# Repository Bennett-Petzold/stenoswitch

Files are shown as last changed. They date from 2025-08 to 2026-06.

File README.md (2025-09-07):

Split stenography keyboard supporting USB, Bluetooth, battery, and embedded Plover translation.

# Warning!!!
There is no warranty, implied or otherwise, on this repository!
This is a hobby project by someone who has no formal education or training in PCB design. 
I _CANNOT_ guarantee that the battery circuit is safe.
I _CANNOT_ guarantee bluetooth communications comply with safety regulations.
I _AM NOT_ liable if you make this project and it is dysfunctional.
Understand that there is a risk of electrical fire due to the lithium ion battery.
Understand that wireless communications are untested and may interfere with pacemakers etc.

# Capabilities
TODO.

# Licenses
All code is licensed under the Mozilla Public License 2.0.
All non-code is licensed under CC BY-SA 4.0.
Both licenses allow for commercial use, but any commercial modification must be licensed under the same terms.
They will not "infect" other proprietary works.

# Subfolders
Each subfolder 

## Assembling the Project
See [assembly/README.md](assembly/README.md).

## PCB
KiCAD designs for printed circuit board.
See [pcb/README.md](pcb/README.md) for more.

## Software
Hardware-independent software built into the machine image.
Specialization to a specific hardware is handled in yocto.
See [software/README.md](software/README.md).

## Yocto Image
This defines the machine-specific image.
See [yocto/README.md](yocto/README.md).

# Releases
Some release resources are manually uploaded.
The initial install is done with the full disk image.
Subsequent updates are done by flashing ONLY the length of the full disk image.

# Appendix

### Steno Resources
* https://www.openstenoproject.org/plover/
* https://plover.wiki/index.php/Plover_Wiki
* https://lapwing.aerick.ca/
* https://www.artofchording.com/
* https://www.openstenoproject.org/learn-plover/home.html

### Approximate Cost
These are based on my costs (including shipping and taxes) September 2025, US address.
* $35 for keyswitches and lube
* $18 for springs
* $12 for battery
* $17 for Raspberry Pi
* $60 for components from DigiKey
* $50 for 5 PCBs both sides, 1 stencil from JLCPCB
Expect ~ $200 for a full single order.
There are electronics and buying in bulk reduces per-board prices.
Shipping is also a significant part of the price in these low quantities.

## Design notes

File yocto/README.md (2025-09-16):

# Build Scripts
* `source yocto/build_env.bash` to enter the build environment interactively.
* `scripts/run_build.bash` to build the distribution and partition.
* `scripts/make_image.bash` to create the disk image.

# Installing the Disk Image
To flash the disk image to media, write _ONLY_ the length of the disk image.
Any remaining space on the device is user scratch and retained between updates.

# Debug SSH over WiFi
## Configuring Connection
Set a static unique local IPv6 address. fd12:3456:789a:1::1 works.

# Build/Release Process
Builds use the upstream hash server to save time.
Yocto images are not currently built in Actions due to the memory requirement.
Contributors are responsible for locally validating Yocto builds.
A local Yocto build is manually added to releases.

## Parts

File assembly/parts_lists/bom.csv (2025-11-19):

Qty | Value | Purchase URL
40 | Cherry MX Style PCB Switch | https://mechanicalkeyboards.com/products/gateron-g-pro-30-silver-45g-linear-pcb-mount
1 | Raspberry Pi Zero v1.3 | https://www.digikey.com/en/products/detail/raspberry-pi/SC1176/15298147
1 | 1043 | https://www.digikey.com/en/products/detail/keystone-electronics/1043/2745669
1 | EVE 35V | https://www.18650batterystore.com/products/eve-35v-18650-3500mah-10a-battery
1 | MP2637GR-P | https://www.digikey.com/en/products/detail/monolithic-power-systems-inc/MP2637GR-P/5298904
1 | BQ27427YZFR | https://www.digikey.com/en/products/detail/texas-instruments/BQ27427YZFR/17748369
1 | 1uF | https://www.digikey.com/en/products/detail/samsung-electro-mechanics/CL21B105KAFNNNE/3886724
1 | RA1H1C112R | https://www.digikey.com/en/products/detail/e-switch/RA1H1C112R/3778069
1 | ERB-RE1R00V | https://www.digikey.com/en/products/detail/panasonic-electronic-components/ERB-RE1R00V/2796790
1 | DMG2305UX-7 | https://www.digikey.com/en/products/detail/diodes-incorporated/DMG2305UX-7/4340667
6 | 10K | https://www.digikey.com/en/products/detail/stackpole-electronics-inc/RMCF0805FT10K0/1760676
3 | SLW-864587-2A-RA-N-D | https://www.digikey.com/en/products/detail/same-sky-formerly-cui-devices/SLW-864587-2A-RA-N-D/24399384
1 | 2.2uH | https://www.digikey.com/en/products/detail/taiyo-yuden/BRL3225T2R2M/2002780
1 | 47nF | https://www.digikey.com/en/products/detail/walsin-technology-corporation/0805B473J500CT/9355080
1 | 20m | https://www.digikey.com/en/products/detail/stackpole-electronics-inc/CSS0805FT20L0/6271917
5 | ESD321DYAR | https://www.digikey.com/en/products/detail/texas-instruments/ESD321DYAR/17394968
3 | TSD05DYFR | https://www.digikey.com/en/products/detail/texas-instruments/TSD05DYFR/21298352
1 | MCP3204T-CI/SL | https://www.digikey.com/en/products/detail/microchip-technology/MCP3204T-CI-SL/319441
6 | 22uF | https://www.digikey.com/en/products/detail/samsung-electro-mechanics/CL31A226KAHNNNE/3888705
30 | 1N4148WX-TP | https://www.mccsemi.com/pdf/Products/1N4148WX(SOD-323).pdf
1 | UJ20-C-H-G-SMT-P16-TR | https://www.digikey.com/en/products/detail/same-sky-formerly-cui-devices/UJ20-C-H-G-SMT-P16-TR/24818595
2 | RJ45 | https://www.digikey.com/en/products/detail/keystone-electronics/942/5638364
1 | 31.6k | https://www.digikey.com/en/products/detail/stackpole-electronics-inc/RMCF0805FT31K6/1713019
1 | 0.1uF | https://www.digikey.com/en/products/detail/yageo/CC0805KRX7R9BB104/302874
1 | MCP40D19T-104E_LT | https://www.digikey.com/en/products/detail/microchip-technology/MCP40D19T-104E-LT/2163913
1 | 15k | https://www.digikey.com/en/products/detail/stackpole-electronics-inc/RMCF0805FT15K0/1760487
4 | 5.1K | https://www.digikey.com/en/products/detail/stackpole-electronics-inc/RNCF0805DTE5K10/6241868
1 | 21.5k | https://www.digikey.com/en/products/detail/stackpole-electronics-inc/RMCF0805FT21K5/1760114
1 | 500K | https://www.digikey.com/en/products/detail/stackpole-electronics-inc/RNCF0805BTE500K/6240086
1 | 73.2k | https://www.digikey.com/en/products/detail/stackpole-electronics-inc/RNCF0805DTE73K2/6241979
1 | 4.02K | https://www.digikey.com/en/products/detail/stackpole-electronics-inc/RNCP0805FTD4K02/2240247
1 | 590k | https://www.digikey.com/en/products/detail/stackpole-electronics-inc/RMCF0805FT590K/1760428
1 | 8.06k | https://www.digikey.com/en/products/detail/stackpole-electronics-inc/RNCP0805FTD8K06/2240259
1 | 7.15K | https://www.digikey.com/en/products/detail/stackpole-electronics-inc/RMCF0805FT7K15/1713329
1 | EG2208 | https://www.digikey.com/en/products/detail/e-switch/EG2208/301963
1 | TLV431BIDBZR | https://www.digikey.com/en/products/detail/texas-instruments/TLV431BIDBZR/705335
1 | 2.2uF | https://www.digikey.com/en/products/detail/tdk-corporation/C2012X7R1C225K125AB/569046
1 | Ferrite Ring | https://www.digikey.com/en/products/detail/epcos-tdk-electronics/B64290P0037X087/3913645
2 | Test Points | https://www.digikey.com/en/products/detail/same-sky-formerly-cui-devices/CPG-45-TH-TR/25666028
1 | 40Pos Header | https://www.digikey.com/en/products/detail/w%C3%BCrth-elektronik/61304021121/4846886

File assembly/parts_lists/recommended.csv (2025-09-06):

Name | Purchase URL
TS391SNL50 Solder Paste | https://www.digikey.com/en/products/detail/chip-quik-inc/TS391SNL50/7802219
18650 Case for Spare Batteries | https://www.18650batterystore.com/products/18650-battery-case-4x-18650
Ethernet Cable | https://www.digikey.com/en/products/detail/assmann-wsw-components/AMJG0808-0050-BKB-26/7653981
20g Springs | https://stenokeyboards.com/products/20-gram-springs
Lube for Springs | https://mechanicalkeyboards.com/products/mk-krytox-205g0-lube-5ml
USB-C Cable | N/A
Keycaps | N/A

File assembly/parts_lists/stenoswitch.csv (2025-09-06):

Reference | Qty | Value | DNP | Exclude from BOM | Exclude from Board | Footprint | Datasheet
A0,Asterisk0,Asterisk1,Asterisk2,Asterisk3,B0,D0,E0,F0,G0,H0,K0,L0,Number_Bar0,Number_Bar1,Number_Bar2,Number_Bar3,Number_Bar4,Number_Bar5,Number_Bar6,Number_Bar7,Number_Bar8,Number_Bar9,Number_Bar10,Number_Bar11,O0,P_{L}0,P_{R}0,R_{L}0,R_{R}0,S0,S1,S2,Spare0,Spare1,T_{L}0,T_{R}0,U0,W0,Z0 | 40 | SW_Push |  |  |  | PCM_Switch_Keyboard_Cherry_MX:SW_Cherry_MX_PCB | ~
A1 | 1 | Raspberry Pi Zero v1.3 |  |  |  | Raspberry_Pi_Zero_v.1.3_Hat:RASPI_ZERO_FULL | https://pinout.xyz/
BAT0 | 1 | 1043 |  |  |  | 1043:BAT_1043
Battery_Charger0 | 1 | MP2637GR-P |  |  |  | QFN-24_MP2637_MNP | https://www.monolithicpower.com/en/documentview/productdocument/index/version/2/document_type/Datasheet/lang/en/sku/MP2637GR-Z
Battery_Monitor0 | 1 | BQ27427YZFR |  |  |  | BQ27427YZFR:IC_BQ27427YZFR
BAT_Decouple0 | 1 | 1uF |  |  |  | Capacitor_SMD:C_0805_2012Metric | https://www.digikey.com/en/products/detail/samsung-electro-mechanics/CL21B105KAFNNNE/3886724
BAT_EN0 | 1 | RA1H1C112R |  |  |  | SW_RA1H1C112R_EWI | RA1H1C112R
BAT_Fuse0 | 1 | ERB-RE1R00V |  |  |  | ultra_librarian_footprints:FUSE_ERBRE_PAN | ERB-RE1R00V
BAT_MIN0 | 1 | DMG2305UX-7 |  |  |  | SOT91P240X110-3N_DMG2305UX-7
BIN_Pulldown0,RNTC_{H}0,RNTC_{L}0,R_{Pullup}0 | 4 | 10K |  |  |  | Resistor_SMD:R_0805_2012Metric | https://www.digikey.com/en/products/detail/stackpole-electronics-inc/RMCF0805FT10K0/1760676
BT_EN0,STORAGE_EN0,TRANSLATION_EN0 | 3 | SLW-864587-2A-RA-N-D |  |  |  | SW_SLW-864587-2A-RA-N-D
CHRG_Bypass0 | 1 | 2.2uH |  |  |  | Inductor_SMD:L_1210_3225Metric | https://www.digikey.com/en/products/detail/taiyo-yuden/BRL3225T2R2M/2002780
CHRG_Decouple0 | 1 | 47nF |  |  |  | Capacitor_SMD:C_0805_2012Metric | https://www.digikey.com/en/products/detail/walsin-technology-corporation/0805B473J500CT/9355080
CHRG_Shunt0 | 1 | 20m |  |  |  | Resistor_SMD:R_0805_2012Metric | https://www.digikey.com/en/products/detail/stackpole-electronics-inc/CSS0805FT20L0/6271917
CR0,CR1,CR2,CR3 | 4 | ESD321DYAR |  |  |  | SOT5x3_DYA_TEX | https://www.ti.com/lit/gpn/esd321
CR4 | 1 | TSD05DYFR |  |  |  | TVS_SOD2_DYF_TEX | https://www.ti.com/lit/gpn/tsd05
Current_Monitor0 | 1 | MCP3204T-CI/SL |  |  |  | SOIC14-N_MC_MCH | MCP3204T-CI/SL
C_{BATT}0,C_{BATT}1,C_{SYS}0,C_{SYS}1,C_{SYS}2,VBUS_Bypass0 | 6 | 22uF |  |  |  | Capacitor_SMD:C_1206_3216Metric | https://www.digikey.com/en/products/detail/samsung-electro-mechanics/CL31A226KAHNNNE/3888705
D_{As}0,D_{AS}1,D_{AS}2,D_{AS}3,D_{A}0,D_{B}0,D_{D}0,D_{E}0,D_{F}0,D_{G}0,D_{H}0,D_{K}0,D_{L}0,D_{NUM}0,D_{NUM}1,D_{O}0,D_{PL}0,D_{PR}0,D_{RL}0,D_{RR}0,D_{Spare}0,D_{Spare}1,D_{S}0,D_{S}1,D_{S}2,D_{TL}0,D_{TR}0,D_{U}0,D_{W}0,D_{Z}0 | 30 | 1N4148WX-TP |  |  |  | Diode_SMD:D_SOD-323 | https://www.mccsemi.com/pdf/Products/1N4148WX(SOD-323).pdf
J0 | 1 | UJ20-C-H-G-SMT-P16-TR |  |  |  | UJ20-C-H-G-SMT-P16-TR:SAMESKY_UJ20-C-H-G-SMT-P16-TR
Left_Plug0,Right_Plug0 | 2 | RJ45 |  |  |  | custom:8P8C_942 | ~
RFB_{H}0 | 1 | 31.6k |  |  |  | Resistor_SMD:R_0805_2012Metric | https://www.digikey.com/en/products/detail/stackpole-electronics-inc/RMCF0805FT31K6/1713019
RFB_{L}0,RLIM_{H}0 | 2 | 10k |  |  |  | Resistor_SMD:R_0805_2012Metric | https://www.digikey.com/en/products/detail/stackpole-electronics-inc/RMCF0805FT10K0/1760676
RLIM_Decouple0 | 1 | 0.1uF |  |  |  | Capacitor_SMD:C_0805_2012Metric | https://www.digikey.com/en/products/detail/yageo/CC0805KRX7R9BB104/302874
RLIM_{L}0 | 1 | MCP40D19T-104E_LT |  |  |  | SOT65P210X110-5N
RREG_{H}0 | 1 | 15k |  |  |  | Resistor_SMD:R_0805_2012Metric | https://www.digikey.com/en/products/detail/stackpole-electronics-inc/RMCF0805FT15K0/1760487
RREG_{L}0,RWIN_{L}0 | 2 | 5.1k |  |  |  | Resistor_SMD:R_0805_2012Metric | https://www.digikey.com/en/products/detail/stackpole-electronics-inc/RMCF0805FT5K10/1760394,https://www.digikey.com/en/products/detail/stackpole-electronics-i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
RWIN_{H}0 | 1 | 21.5k |  |  |  | Resistor_SMD:R_0805_2012Metric | https://www.digikey.com/en/products/detail/stackpole-electronics-inc/RMCF0805FT21K5/1760114
R_{HIST}0 | 1 | 500K |  |  |  | Resistor_SMD:R_0805_2012Metric | https://www.digikey.com/en/products/detail/stackpole-electronics-inc/RNCF0805BTE500K/6240086
R_{ISET}0 | 1 | 73.2k |  |  |  | Resistor_SMD:R_0805_2012Metric | https://www.digikey.com/en/products/detail/stackpole-electronics-inc/RNCF0805DTE73K2/6241979
R_{Lower}0 | 1 | 4.02K |  |  |  | Resistor_SMD:R_0805_2012Metric | https://www.digikey.com/en/products/detail/stackpole-electronics-inc/RNCP0805FTD4K02/2240247
R_{OLIM}0 | 1 | 590k |  |  |  | Resistor_SMD:R_0805_2012Metric | https://www.digikey.com/en/products/detail/stackpole-electronics-inc/RMCF0805FT590K/1760428
R_{Store}0 | 1 | 8.06k |  |  |  | Resistor_SMD:R_0805_2012Metric | https://www.digikey.com/en/products/detail/stackpole-electronics-inc/RNCP0805FTD8K06/2240259
R_{Upper}0 | 1 | 7.15K |  |  |  | Resistor_SMD:R_0805_2012Metric | https://www.digikey.com/en/products/detail/stackpole-electronics-inc/RMCF0805FT7K15/1713329
STORE_EN0 | 1 | EG2208 |  |  |  | SW_EG2208
USB_Default_Power_CC1,USB_Default_Power_CC2 | 2 | 5.1K |  |  |  | Resistor_SMD:R_0805_2012Metric | https://www.digikey.com/en/products/detail/stackpole-electronics-inc/RNCF0805DTE5K10/6241868
VBAT_PASS0 | 1 | TLV431BIDBZR |  |  |  | DBZ3 | https://www.ti.com/lit/gpn/tlv431b
VDD_Decouple0 | 1 | 2.2uF |  |  |  | Capacitor_SMD:C_0805_2012Metric | https://www.digikey.com/en/products/detail/tdk-corporation/C2012X7R1C225K125AB/569046

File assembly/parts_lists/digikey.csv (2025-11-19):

Qty | Part Number
1 | 2648-SC1176-ND
1 | 36-1043-ND
1 | 1589-1147-1-ND
1 | 296-BQ27427YZFRCT-ND
1 | 1276-1066-1-ND
1 | EG5626-ND
1 | P15124CT-ND
1 | DMG2305UX-7DICT-ND
6 | RMCF0805FT10K0CT-ND
3 | 2223-SLW-864587-2A-RA-N-D-ND
1 | 587-2165-1-ND
1 | 1292-1583-1-ND
1 | 738-CSS0805FT20L0CT-ND
5 | 296-ESD321DYARCT-ND
3 | 296-TSD05DYFRCT-ND
1 | MCP3204T-CI/SLCT-ND
6 | 1276-3047-1-ND
30 | 1N4148WXTPMSCT-ND
1 | 2223-UJ20-C-H-G-SMT-P16-TRCT-ND
2 | 36-942-ND
1 | RMCF0805FT31K6CT-ND
1 | 311-1140-1-ND
1 | MCP40D19T-104E/LTCT-ND
1 | RMCF0805FT15K0CT-ND
4 | 738-RNCF0805DTE5K10CT-ND
1 | 738-RMCF0805FT21K5CT-ND
1 | 738-RNCF0805BTE500KCT-ND
1 | 738-RNCF0805DTE73K2CT-ND
1 | RNCP0805FTD4K02CT-ND
1 | 738-RMCF0805FT590KCT-ND
1 | RNCP0805FTD8K06CT-ND
1 | RMCF0805FT7K15CT-ND
1 | EG1941-ND
1 | 296-17571-1-ND
1 | 445-1420-1-ND
2 | 2223-CPG-45-TH-TRCT-ND
1 | 61304021121
1 | B64290P0037X087

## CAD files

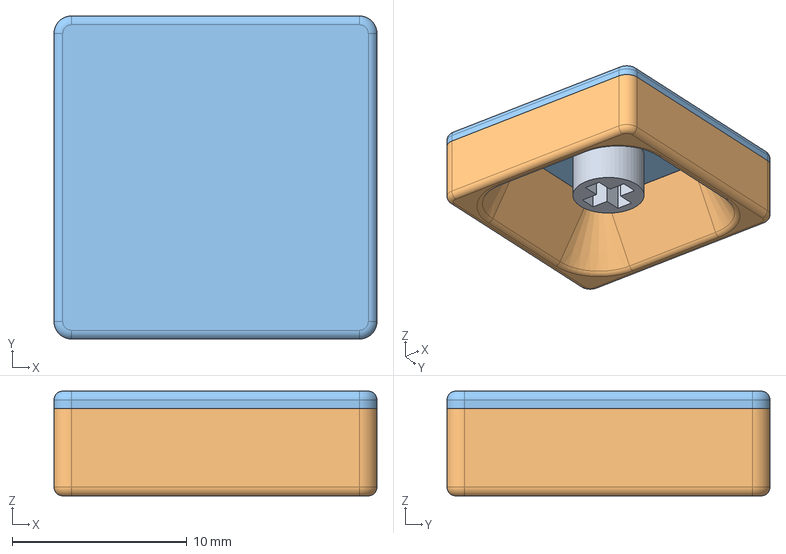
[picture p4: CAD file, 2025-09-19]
assembly/keycap/keycap.FCStd
18.5 x 18.5 x 6.00 mm
Stem001
Shell Bottom
ShellTop001

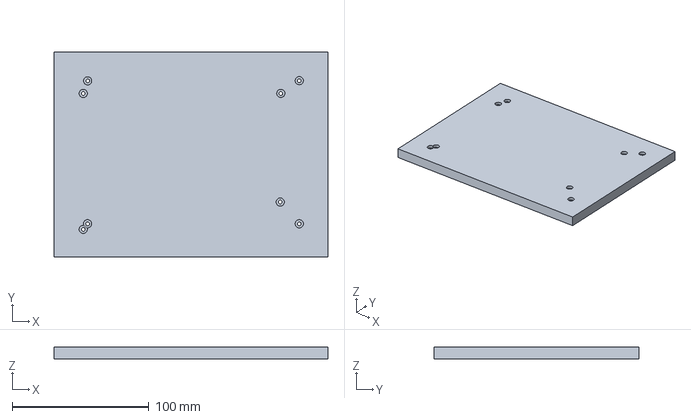
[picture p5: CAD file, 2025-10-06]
assembly/printed_aids/base_plate/base_plate.FCStd
200.0 x 150.0 x 9.00 mm

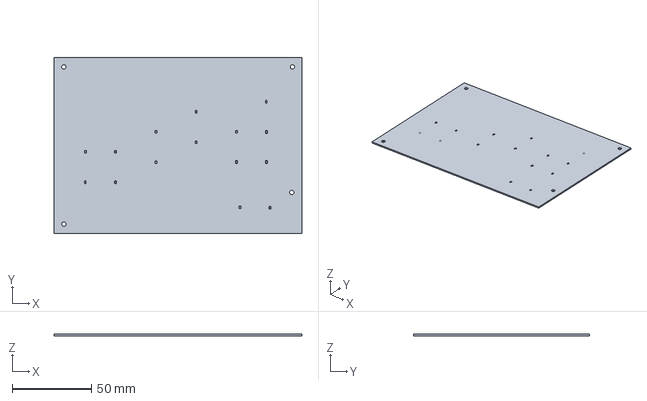
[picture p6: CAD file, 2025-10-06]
assembly/printed_aids/left_hand_plate/left_hand_plate.FCStd
156.4 x 110.8 x 1.00 mm

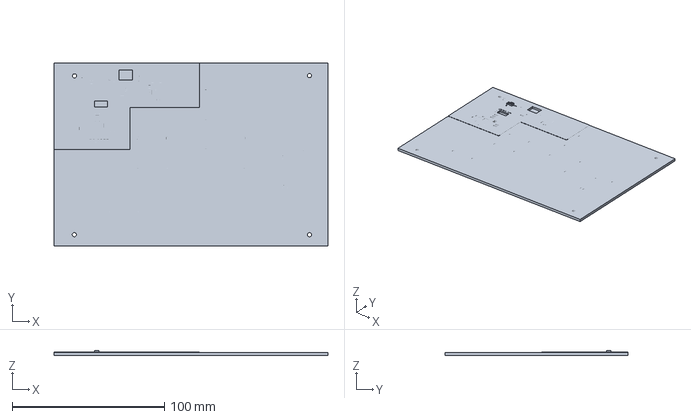
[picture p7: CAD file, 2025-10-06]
assembly/printed_aids/right_hand_plate/right_hand_plate.3mf
180.0 x 120.0 x 3.40 mm

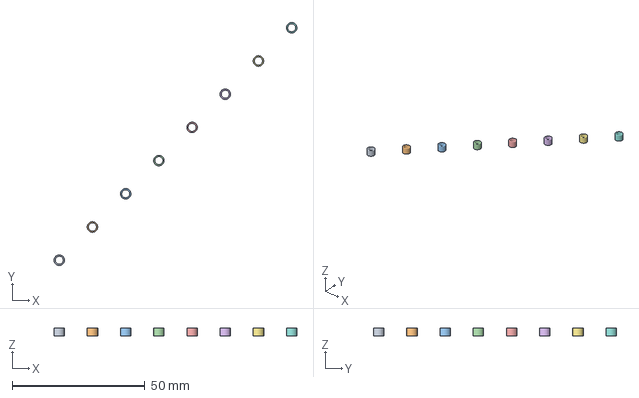
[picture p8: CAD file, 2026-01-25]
assembly/printed_aids/spacer/8spacer.3mf
91.5 x 91.5 x 3.10 mm

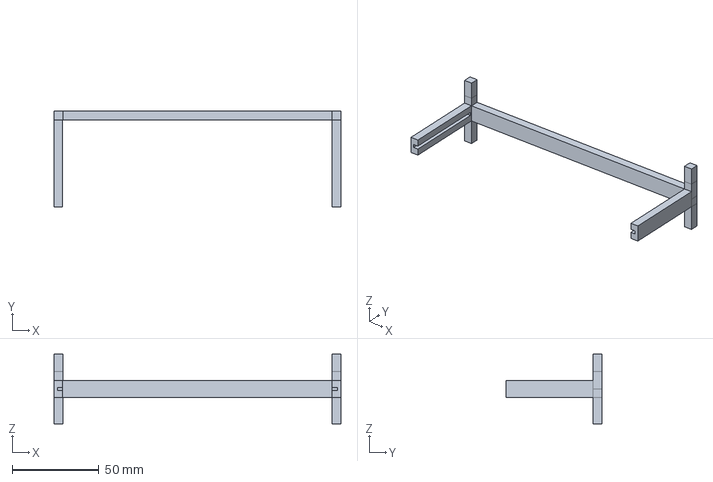
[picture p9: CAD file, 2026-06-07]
assembly/printed_aids/stand/stand.FCStd
165.0 x 55.0 x 40.0 mm

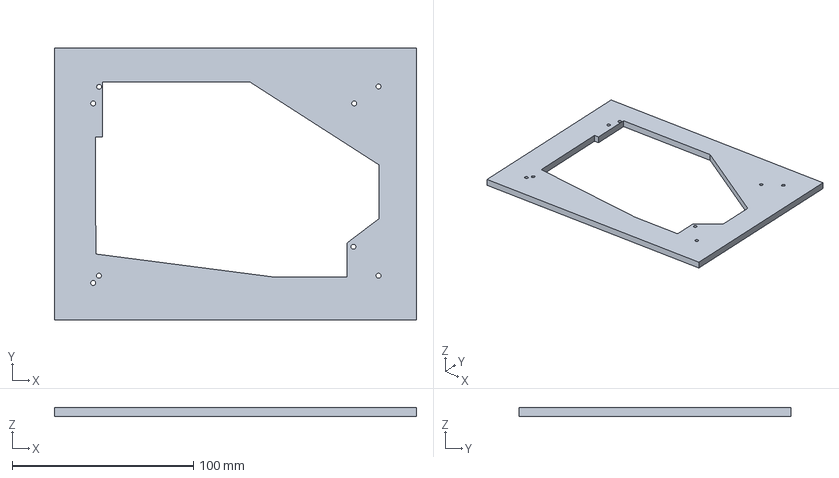
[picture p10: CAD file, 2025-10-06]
assembly/printed_aids/stencil_plate/stencil_plate.FCStd
200.0 x 150.0 x 5.00 mm

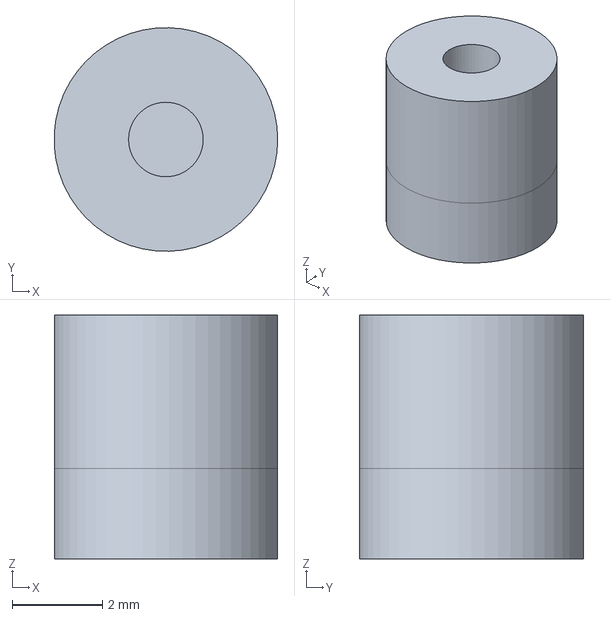
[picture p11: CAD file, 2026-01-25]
assembly/printed_aids/test_point_alignment/test_point_alignment_2.FCStd
4.95 x 4.95 x 5.40 mm

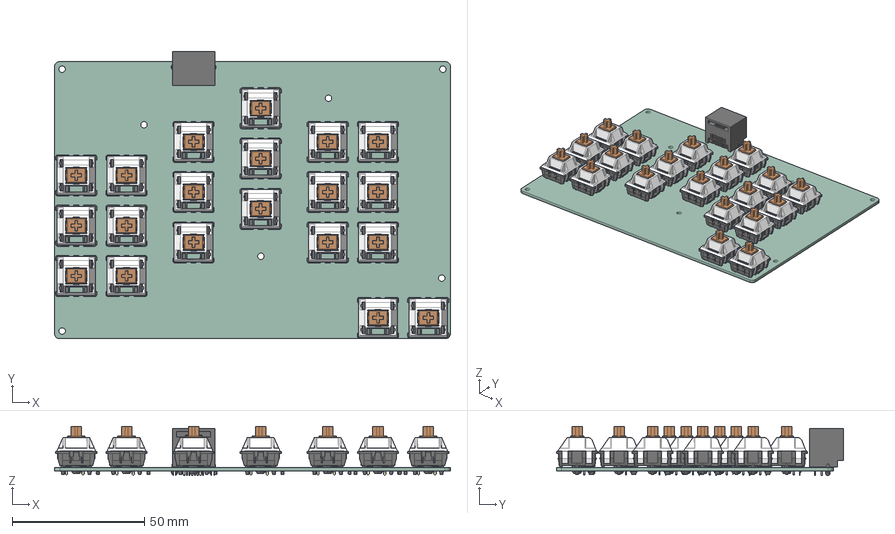
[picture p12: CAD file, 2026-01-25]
pcb/left_hand/left_hand.step
150.0 x 108.9 x 18.7 mm
SW_Cherry_MX_PCB x 20
D_SOD-323 x 15
left_hand_PCB

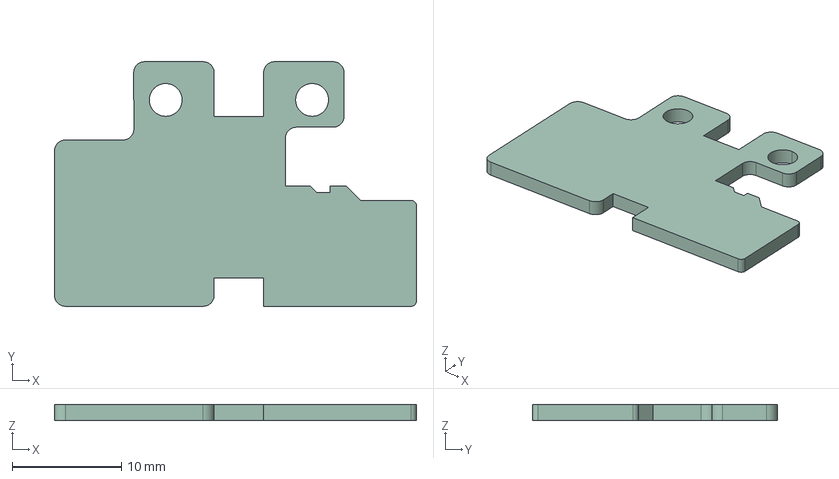
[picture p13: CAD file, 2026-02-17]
pcb/microsd_flipper/microsd_flipper.step
33.2 x 22.4 x 1.51 mm

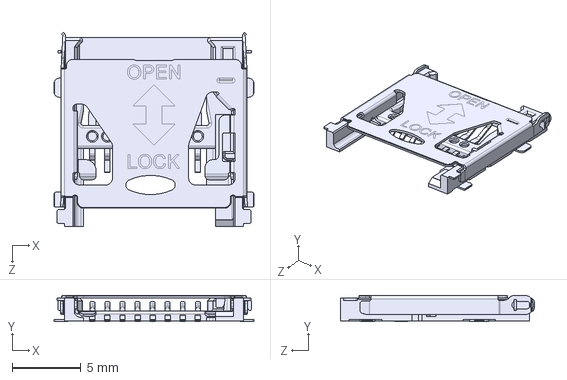
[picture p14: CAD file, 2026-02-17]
pcb/resources/snap_magic/MSD-10-C.step
14.6 x 1.90 x 14.2 mm

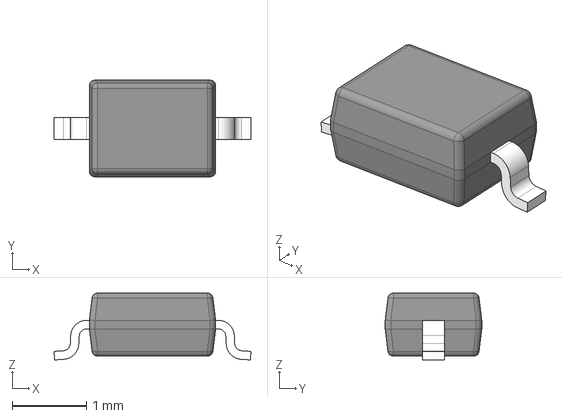
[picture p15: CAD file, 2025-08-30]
pcb/resources/ultra_librarian/DYF0002A.stp
2.65 x 1.30 x 0.9 mm
BODY-SOT
LEAD-SOT x 2

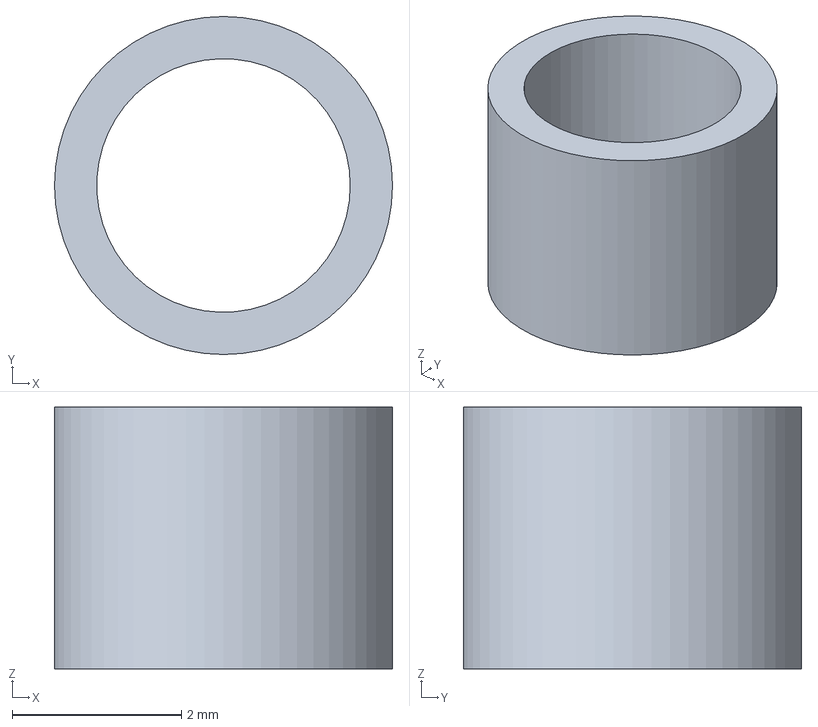
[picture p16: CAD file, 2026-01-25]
assembly/printed_aids/spacer/spacer.FCStd
4.00 x 4.00 x 3.10 mm

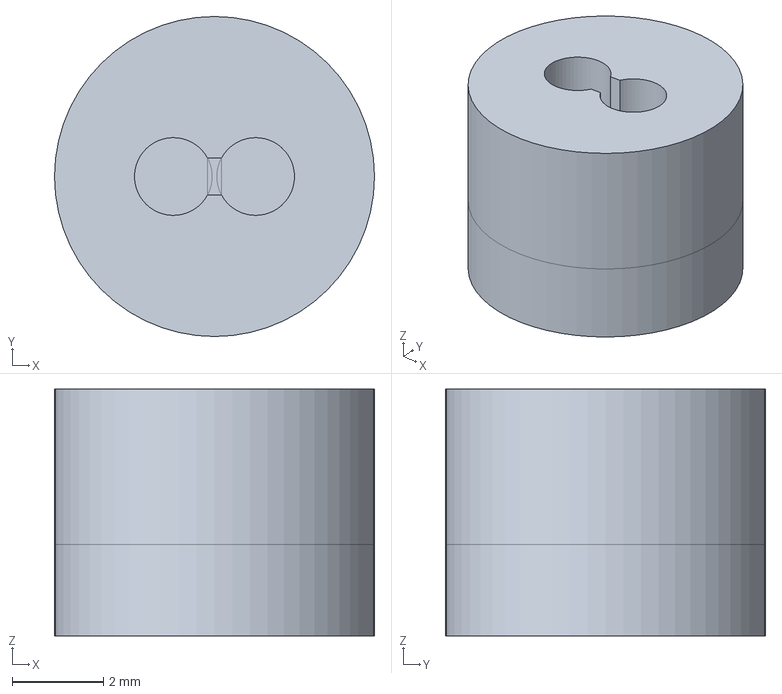
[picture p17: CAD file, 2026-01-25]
assembly/printed_aids/test_point_alignment/test_point_alignment_3.FCStd
7.00 x 7.00 x 5.40 mm

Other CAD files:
pcb/resources/snap_magic/UJ20-C-H-G-SMT-P16-TR.step
pcb/resources/ultra_librarian/DPL0002A.stp
assembly/printed_aids/test_point_alignment/test_point_alignment.FCStd
pcb/resources/snap_magic/0926-1-15-20-75-14-11-0.step
assembly/keycap/keycap.stl
assembly/printed_aids/base_plate/base_plate.3mf
assembly/printed_aids/base_plate/base_plate.stl
assembly/printed_aids/left_hand_plate/left_hand_plate.3mf
assembly/printed_aids/left_hand_plate/left_hand_plate.stl
assembly/printed_aids/right_hand_plate/right_hand_plate.stl
assembly/printed_aids/spacer/spacer.stl
assembly/printed_aids/stand/stand.3mf
assembly/printed_aids/stand/stand.stl
assembly/printed_aids/stencil_plate/stencil_plate.3mf
assembly/printed_aids/stencil_plate/stencil_plate.stl
assembly/printed_aids/test_point_alignment/test_point_alignment.3mf
assembly/printed_aids/test_point_alignment/test_point_alignment.stl
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

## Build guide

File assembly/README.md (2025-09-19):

TODO

## Keyswitches

#### Keyswitch Opener
https://www.printables.com/model/641731-over-engineered-3d-printed-switch-opener

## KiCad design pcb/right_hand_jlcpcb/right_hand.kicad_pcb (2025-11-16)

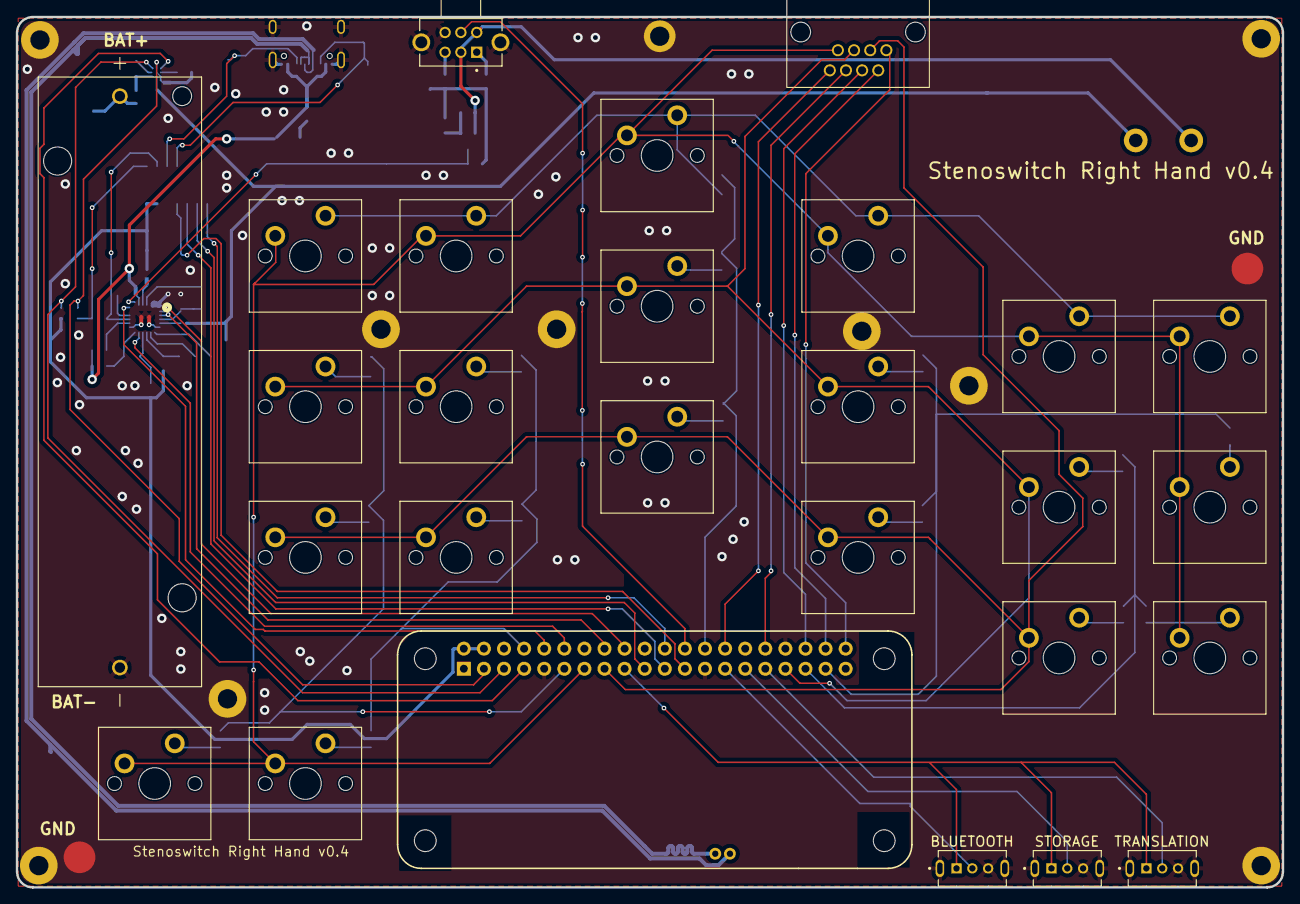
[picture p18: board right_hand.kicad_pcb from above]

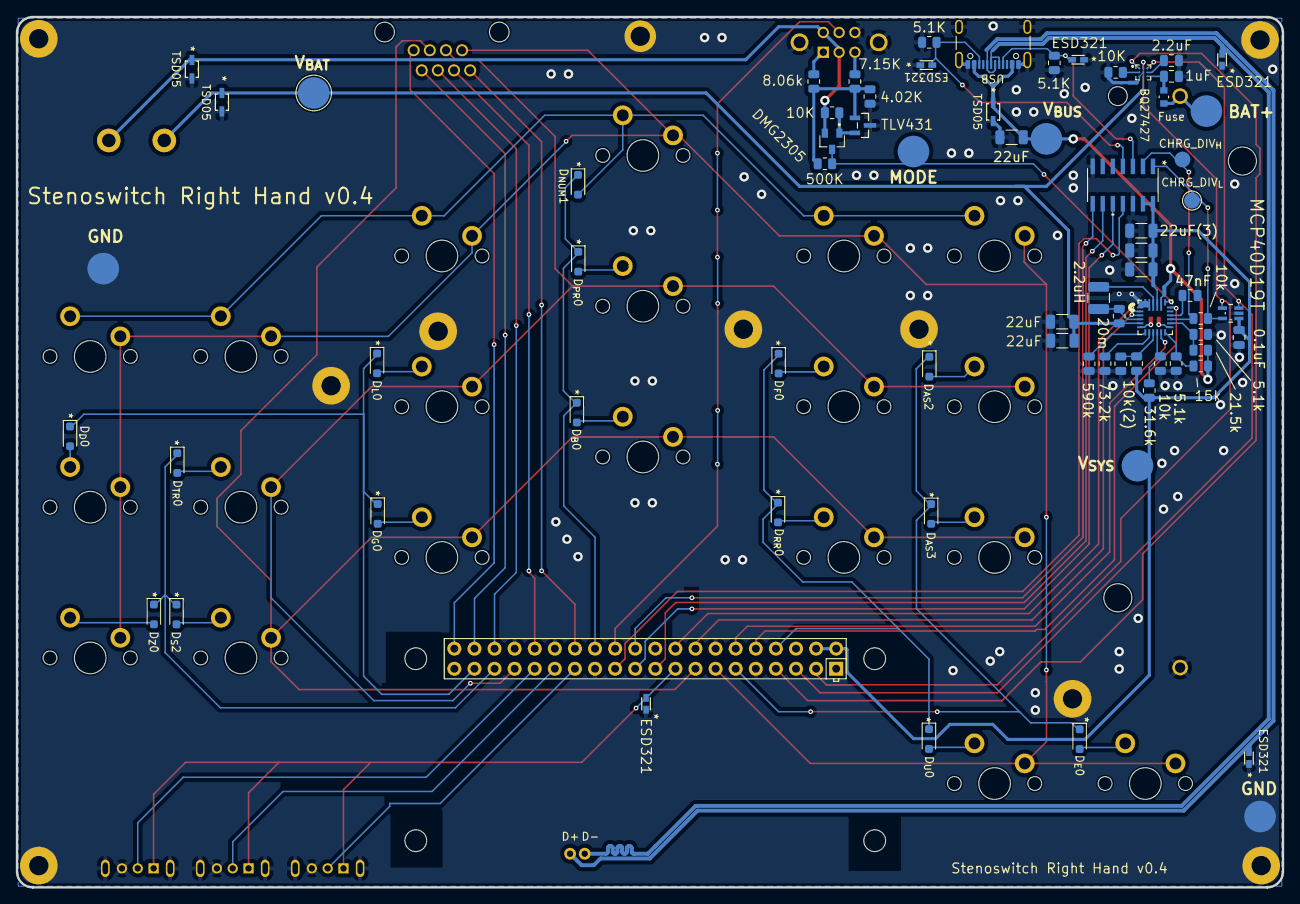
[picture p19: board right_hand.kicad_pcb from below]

Board: 2 copper layers, 160.0 x 110.0 mm, 96 parts (67 on the bottom side), 78 nets.

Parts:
A1: Raspberry Pi Zero v1.3; RASPI_ZERO_FULL
Asterisk2, Asterisk3: SW_Push; SW_Cherry_MX_PCB
B0: SW_Push; SW_Cherry_MX_PCB
BAT0: 1043; BAT_1043
BAT_Decouple0: 1uF; C_0805_2012Metric
BAT_EN0: RA1H1C112R; SW_RA1H1C112R_EWI
BAT_Fuse0: 2.5 A; FUSE_ERBRE_PAN
BAT_MIN0: DMG2305UX-7; SOT91P240X110-3N_DMG2305UX-7
BIN_Pulldown0: 10K; R_0805_2012Metric
BLUETOOTH: SLW-864587-2A-RA-N-D; SW_SLW-864587-2A-RA-N-D
Battery_Charger0: MP2637GR-P; QFN-24_MP2637_MNP
Battery_Monitor0: BQ27427YZFR; IC_BQ27427YZFR
CHRG_Bypass0: 2.2uH; L_1210_3225Metric
CHRG_DIV_{L}: TestPoint_Pad_D2.0mm
CHRG_Decouple0: 47nF; C_0805_2012Metric
CHRG_Shunt0: 20m; R_0805_2012Metric
CR0, CR1, CR3, CR4, CR5: ESD321DYAR; SOT5x3_DYA_TEX
CR2, CR6, CR7: TSD05DYFR; TVS_SOD2_DYF_TEX
C_{BATT}0, C_{BATT}1: 22uF; C_1206_3216Metric
C_{SYS}0, C_{SYS}1, C_{SYS}2: 22uF; C_1206_3216Metric
Current_Monitor1: MCP3204T-CI/SL; SOIC14-N_MC_MCH
D0: SW_Push; SW_Cherry_MX_PCB
D_{AS}2, D_{AS}3: 1N4148WX-TP; D_SOD-323_HandSoldering
D_{B}0: 1N4148WX-TP; D_SOD-323_HandSoldering
D_{D}0: 1N4148WX-TP; D_SOD-323_HandSoldering
D_{E}0: 1N4148WX-TP; D_SOD-323_HandSoldering
D_{F}0: 1N4148WX-TP; D_SOD-323_HandSoldering
D_{G}0: 1N4148WX-TP; D_SOD-323_HandSoldering
D_{L}0: 1N4148WX-TP; D_SOD-323_HandSoldering
D_{NUM}1: 1N4148WX-TP; D_SOD-323_HandSoldering
D_{PR}0: 1N4148WX-TP; D_SOD-323_HandSoldering
D_{RR}0: 1N4148WX-TP; D_SOD-323_HandSoldering
D_{S}2: 1N4148WX-TP; D_SOD-323_HandSoldering
D_{TR}0: 1N4148WX-TP; D_SOD-323_HandSoldering
D_{U}0: 1N4148WX-TP; D_SOD-323_HandSoldering
D_{Z}0: 1N4148WX-TP; D_SOD-323_HandSoldering
E0: SW_Push; SW_Cherry_MX_PCB
F0: SW_Push; SW_Cherry_MX_PCB
G0: SW_Push; SW_Cherry_MX_PCB
L0: SW_Push; SW_Cherry_MX_PCB
NT0, NT1, NT2, NT3, NT4: NetTie_2; NetTie-2_SMD_Pad0.5mm
Number_Bar6, Number_Bar7, Number_Bar8, Number_Bar9, Number_Bar10, Number_Bar11: SW_Push; SW_Cherry_MX_PCB
P_{R}0: SW_Push; SW_Cherry_MX_PCB
RFB_{H}0: 31.6k; R_0805_2012Metric
RFB_{L}0: 10k; R_0805_2012Metric
RLIM_Decouple0: 0.1uF; C_0805_2012Metric
RLIM_{H}0: 10k; R_0805_2012Metric
RLIM_{L}0: MCP40D19T-104E_LT; SOT65P210X110-5N
RNTC_{H}0: 10k; R_0805_2012Metric
RNTC_{L}0: 10k; R_0805_2012Metric
RREG_{H}0: 15k; R_0805_2012Metric
RREG_{L}0: 5.1k; R_0805_2012Metric
RWIN_{H}0: 21.5k; R_0805_2012Metric
RWIN_{L}0: 5.1k; R_0805_2012Metric
R_{HIST}0: 500K; R_0805_2012Metric
R_{ISET}0: 73.2k; R_0805_2012Metric
R_{Lower}0: 4.02K; R_0805_2012Metric
R_{OLIM}0: 590k; R_0805_2012Metric
R_{Pullup}0: 10K; R_0805_2012Metric
R_{R}0: SW_Push; SW_Cherry_MX_PCB
R_{Store}0: 8.06k; R_0805_2012Metric
R_{Upper}0: 7.15K; R_0805_2012Metric
Right_Plug0: RJ45; 8P8C_942
S2: SW_Push; SW_Cherry_MX_PCB
STORAGE: SLW-864587-2A-RA-N-D; SW_SLW-864587-2A-RA-N-D
STORE_EN0: EG2208; SW_EG2208
TRANSLATION: SLW-864587-2A-RA-N-D; SW_SLW-864587-2A-RA-N-D
T_{R}0: SW_Push; SW_Cherry_MX_PCB
U0: SW_Push; SW_Cherry_MX_PCB
USB0: USB4105-GF-A; USB_C_Receptacle_GCT_USB4105-xx-A_16P_TopMnt_Horizontal
USB_Default_Power_CC1, USB_Default_Power_CC2: 5.1K; R_0805_2012Metric
VBAT_PASS0: TLV431BIDBZR; DBZ3
VBUS_Bypass0: 22uF; C_1206_3216Metric
VDD_Decouple0: 2.2uF; C_0805_2012Metric
Z0: SW_Push; SW_Cherry_MX_PCB

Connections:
/Control/ALERT_{BATMON}: A1.7 (GP4), Battery_Monitor0.A1 (GPOUT)
/Control/BAT_{ON}: A1.16 (GP23), Battery_Charger0.3 (*BOOST)
/Control/CHG_{EN}: A1.10 (GP15/RXD), Battery_Charger0.18 (EN)
/Control/CHG_{ON}: A1.18 (GP24), Battery_Charger0.2 (*CHG)
/Control/CLK_{CURRENT}: A1.23 (GP11/SCLK), Current_Monitor1.11 (CLK)
/Control/CS_{CURRENT}: A1.22 (GP25), Current_Monitor1.8 (*CS/SHDN)
/Control/DIN_{CURRENT}: A1.19 (GP10/MOSI), Current_Monitor1.9 (DIN)
/Control/DOUT_{CURRENT}: A1.21 (GP9/MISO), Current_Monitor1.10 (DOUT)
/Control/Data_N: A1.PP23 (USB_D-), CR0.1, USB0.A7 (D-), USB0.B7 (D-)
/Control/Data_P: A1.PP22 (USB_D+), CR1.1, USB0.A6 (D+), USB0.B6 (D+)
/Control/Right_Columns0: A1.35 (GP19), D_{S}2.1 (K), D_{TR}0.1 (K), D_{Z}0.1 (K)
/Control/Right_Columns1: A1.37 (GP26), D_{D}0.1 (K), D_{G}0.1 (K), D_{L}0.1 (K)
/Control/Right_Columns2: A1.26 (GP7/CS1), D_{B}0.1 (K), D_{NUM}1.1 (K), D_{PR}0.1 (K)
/Control/Right_Columns3: A1.8 (GP14/TXD), D_{F}0.1 (K), D_{RR}0.1 (K), D_{U}0.1 (K)
/Control/Right_Columns4: A1.11 (GP17), D_{AS}2.1 (K), D_{AS}3.1 (K), D_{E}0.1 (K)
/Control/SCL: A1.5 (GP3/SCL), Battery_Monitor0.A3 (SCL), RLIM_{L}0.3 (SCL)
/Control/SDA: A1.3 (GP2/SDA), Battery_Monitor0.A2 (SDA), RLIM_{L}0.4 (SDA)
/Control/STORE_{ON}: A1.24 (GP8/CS0), STORE_EN0.5
/Control/USB_{ON}: A1.12 (GP18), Battery_Charger0.11 (*ACOK)
/Control/V_{SYS}: A1.2 (+5V), A1.4 (+5V), C_{SYS}0.1, C_{SYS}1.1, C_{SYS}2.1, Current_Monitor1.13 (VREF), Current_Monitor1.14 (VDD), NT0.1, RFB_{H}0.2, RLIM_Decouple0.1, RLIM_{L}0.1 (VDD), RNTC_{H}0.1
/Interface/Battery/CHRG_DIV_{H}: Battery_Charger0.15 (ILIM), Current_Monitor1.2 (CH1), RLIM_{H}0.1
/Interface/Battery/CHRG_DIV_{L}: CHRG_DIV_{L}.1, Current_Monitor1.1 (CH0), RLIM_{H}0.2, RLIM_{L}0.5 (W)
/Interface/Battery/V_{BUS}: CR2.1 (I/O), NT1.2, RREG_{H}0.1, RWIN_{H}0.1, USB0.A4 (VBUS), USB0.A9 (VBUS), USB0.B4 (VBUS), USB0.B9 (VBUS), VBUS_Bypass0.1
/Left_Columns0: A1.28 (GP1), Right_Plug0.4
/Left_Columns1: A1.32 (GP12/PWM0), Right_Plug0.3
/Left_Columns2: A1.36 (GP16), Right_Plug0.2
/Left_Columns3: A1.38 (GP20), Right_Plug0.1
/Left_Columns4: A1.40 (GP21), Right_Plug0.5
/Rows0: A1.33 (GP13/PWM1), Asterisk2.1, F0.1, L0.1, P_{R}0.1, Right_Plug0.7, T_{R}0.1
/Rows1: A1.15 (GP22), Asterisk3.1, B0.1, G0.1, R_{R}0.1, Right_Plug0.6, S2.1
/Rows2: A1.13 (GP27), D0.1, E0.1, Number_Bar6.1, Number_Bar7.1, Number_Bar8.1, Number_Bar9.1, Number_Bar10.1, Number_Bar11.1, Right_Plug0.8, U0.1, Z0.1
GND: A1.9 (GND), A1.14 (GND), A1.25 (GND), A1.30 (GND), A1.34 (GND), BAT0.N, BAT_Decouple0.2, BIN_Pulldown0.1, BLUETOOTH.3, BLUETOOTH.SH1, BLUETOOTH.SH2, Battery_Charger0.1 (PGND), Battery_Charger0.23 (PGND), Battery_Charger0.24 (PGND), CHRG_Decouple0.2, CR0.2, CR1.2, CR2.2 (GND), CR3.2, CR4.2, CR5.2, CR6.2 (GND), CR7.2 (GND), C_{BATT}0.2, C_{BATT}1.2, C_{SYS}0.2, C_{SYS}1.2, C_{SYS}2.2, Current_Monitor1.7 (DGND), Current_Monitor1.12 (AGND), NT2.1, NT3.2, NT4.2, RFB_{L}0.1, RLIM_Decouple0.2, RLIM_{L}0.2 (VSS), RNTC_{L}0.2, RREG_{L}0.2, RWIN_{L}0.2, R_{ISET}0.2, R_{Lower}0.2, R_{OLIM}0.2, STORAGE.3, STORAGE.SH1, STORAGE.SH2, STORE_EN0.6, STORE_EN0.S1, STORE_EN0.S2, TRANSLATION.3, TRANSLATION.SH1, TRANSLATION.SH2, USB0.A1 (GND), USB0.A12 (GND), USB0.B1 (GND), USB0.B12 (GND), USB0.S1 (SHIELD), USB_Default_Power_CC1.2, USB_Default_Power_CC2.2, VBAT_PASS0.3 (ANODE), VBUS_Bypass0.2, VDD_Decouple0.2
unnamed: A1.17 (+3V3), BLUETOOTH.1, CR5.1, STORAGE.1, TRANSLATION.1
unnamed: A1.27 (GP0), BLUETOOTH.2
unnamed: A1.29 (GP5), STORAGE.2
unnamed: A1.31 (GP6), TRANSLATION.2
unnamed: BAT0.P, BAT_Fuse0.2
unnamed: Battery_Charger0.6 (AGND), NT4.1
unnamed: BAT_EN0.2, Battery_Charger0.5 (BATT), Battery_Monitor0.C2 (SRX), CHRG_Shunt0.1, CR6.1 (I/O), C_{BATT}0.1, C_{BATT}1.1
unnamed: Battery_Charger0.4 (CSP), CHRG_Bypass0.1, CHRG_Shunt0.2
unnamed: Battery_Charger0.10 (FB), RFB_{H}0.1, RFB_{L}0.2
unnamed: Battery_Charger0.8 (ISET), R_{ISET}0.1
unnamed: BAT_MIN0.3, Battery_Charger0.19 (MODE), R_{HIST}0.1
unnamed: Battery_Charger0.9 (NTC), RNTC_{H}0.2, RNTC_{L}0.1
unnamed: Battery_Charger0.7 (OLIM), R_{OLIM}0.1
unnamed: Battery_Charger0.14 (PWIN), RWIN_{H}0.2, RWIN_{L}0.1
unnamed: Battery_Charger0.12 (REG), RREG_{H}0.2, RREG_{L}0.1
unnamed: Battery_Charger0.22 (SW), CHRG_Bypass0.2
unnamed: Battery_Charger0.21 (SYS), NT0.2
unnamed: Battery_Charger0.13 (TMR), NT3.1
unnamed: Battery_Charger0.16 (VCC), CHRG_Decouple0.1
unnamed: Battery_Charger0.20 (VIN), NT1.1
unnamed: BAT_Decouple0.1, BAT_Fuse0.1, Battery_Monitor0.C3 (BAT)
unnamed: BIN_Pulldown0.2, Battery_Monitor0.B1 (BIN)
unnamed: Battery_Monitor0.B3 (VDD), VDD_Decouple0.1
unnamed: Battery_Monitor0.B2 (VSS), Battery_Monitor0.C1 (VSS__1), NT2.2
unnamed: BAT_EN0.1, BAT_MIN0.2, CR7.1 (I/O), R_{Pullup}0.1, STORE_EN0.2, STORE_EN0.4
unnamed: CR3.1, Current_Monitor1.3 (CH2), USB0.B5 (CC2), USB_Default_Power_CC2.1
unnamed: CR4.1, Current_Monitor1.4 (CH3), USB0.A5 (CC1), USB_Default_Power_CC1.1
unnamed: Asterisk2.2, D_{AS}2.2 (A)
unnamed: Asterisk3.2, D_{AS}3.2 (A)
unnamed: B0.2, D_{B}0.2 (A)
unnamed: D0.2, D_{D}0.2 (A)
unnamed: D_{E}0.2 (A), E0.2
unnamed: D_{F}0.2 (A), F0.2
unnamed: D_{G}0.2 (A), G0.2
unnamed: D_{L}0.2 (A), L0.2
unnamed: D_{NUM}1.2 (A), Number_Bar6.2, Number_Bar7.2, Number_Bar8.2, Number_Bar9.2, Number_Bar10.2, Number_Bar11.2
unnamed: D_{PR}0.2 (A), P_{R}0.2
unnamed: D_{RR}0.2 (A), R_{R}0.2
unnamed: D_{S}2.2 (A), S2.2
unnamed: D_{TR}0.2 (A), T_{R}0.2
unnamed: D_{U}0.2 (A), U0.2
unnamed: D_{Z}0.2 (A), Z0.2
unnamed: R_{Store}0.1, STORE_EN0.1
unnamed: R_{Upper}0.1, STORE_EN0.3
unnamed: BAT_MIN0.1, R_{Pullup}0.2, VBAT_PASS0.2 (CATHODE)
unnamed: R_{HIST}0.2, R_{Lower}0.1, R_{Store}0.2, R_{Upper}0.2, VBAT_PASS0.1 (REF)

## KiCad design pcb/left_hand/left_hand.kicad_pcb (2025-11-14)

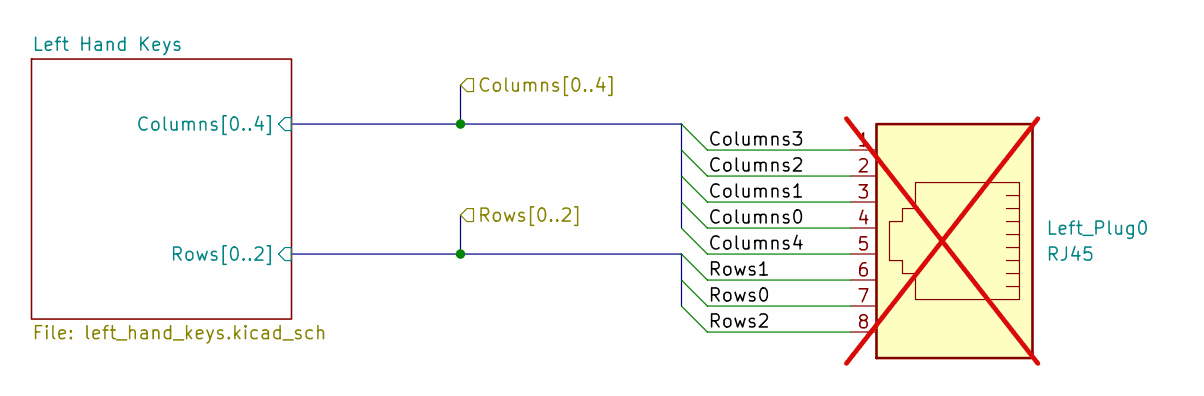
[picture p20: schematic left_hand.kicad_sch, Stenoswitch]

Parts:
Left_Plug0: RJ45; 8P8C_942; not fitted

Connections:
/Columns0: Left_Plug0.4; also elsewhere on the board
/Columns1: Left_Plug0.3; also elsewhere on the board
/Columns2: Left_Plug0.2; also elsewhere on the board
/Columns3: Left_Plug0.1; also elsewhere on the board
/Columns4: Left_Plug0.5; also elsewhere on the board
/Rows0: Left_Plug0.7; also elsewhere on the board
/Rows1: Left_Plug0.6; also elsewhere on the board
/Rows2: Left_Plug0.8; also elsewhere on the board

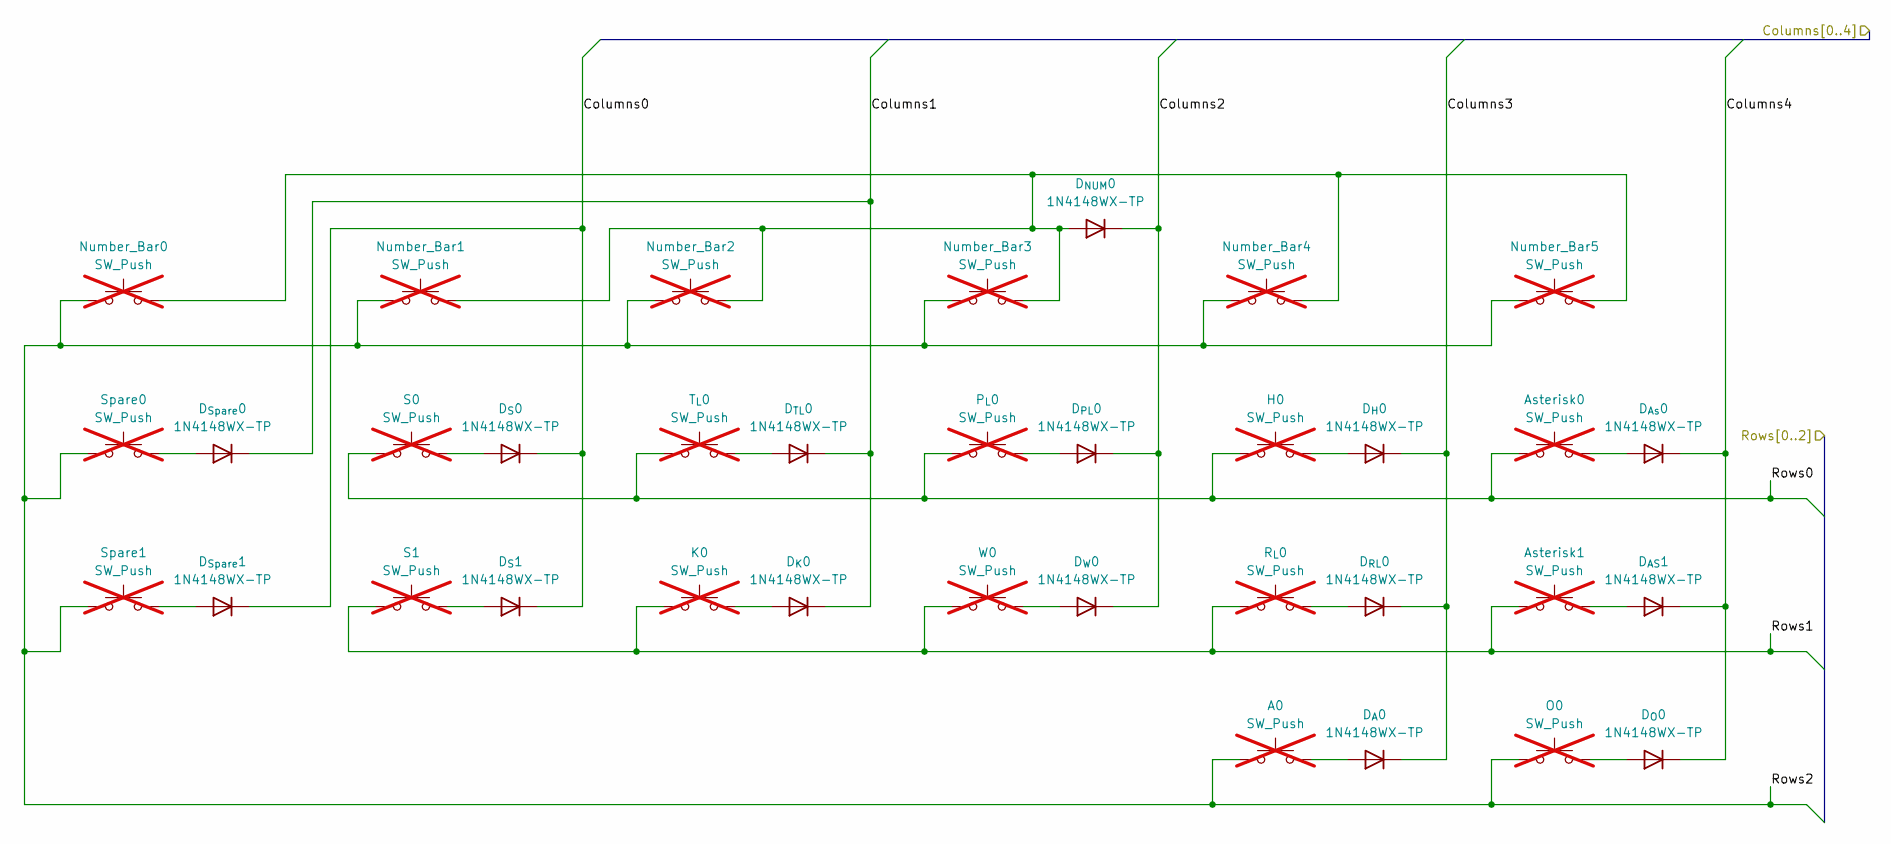
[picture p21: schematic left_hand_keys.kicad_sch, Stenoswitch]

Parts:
A0: SW_Push; SW_Cherry_MX_PCB; not fitted
Asterisk0, Asterisk1: SW_Push; SW_Cherry_MX_PCB; not fitted
D_{AS}1: 1N4148WX-TP; D_SOD-323; LCSC C78740
D_{As}0: 1N4148WX-TP; D_SOD-323; LCSC C78740
D_{A}0: 1N4148WX-TP; D_SOD-323; LCSC C78740
D_{H}0: 1N4148WX-TP; D_SOD-323; LCSC C78740
D_{K}0: 1N4148WX-TP; D_SOD-323; LCSC C78740
D_{NUM}0: 1N4148WX-TP; D_SOD-323; LCSC C78740
D_{O}0: 1N4148WX-TP; D_SOD-323; LCSC C78740
D_{PL}0: 1N4148WX-TP; D_SOD-323; LCSC C78740
D_{RL}0: 1N4148WX-TP; D_SOD-323; LCSC C78740
D_{Spare}0, D_{Spare}1: 1N4148WX-TP; D_SOD-323; LCSC C78740
D_{S}0, D_{S}1: 1N4148WX-TP; D_SOD-323; LCSC C78740
D_{TL}0: 1N4148WX-TP; D_SOD-323; LCSC C78740
D_{W}0: 1N4148WX-TP; D_SOD-323; LCSC C78740
H0: SW_Push; SW_Cherry_MX_PCB; not fitted
K0: SW_Push; SW_Cherry_MX_PCB; not fitted
Number_Bar0, Number_Bar1, Number_Bar2, Number_Bar3, Number_Bar4, Number_Bar5: SW_Push; SW_Cherry_MX_PCB; not fitted
O0: SW_Push; SW_Cherry_MX_PCB; not fitted
P_{L}0: SW_Push; SW_Cherry_MX_PCB; not fitted
R_{L}0: SW_Push; SW_Cherry_MX_PCB; not fitted
S0, S1: SW_Push; SW_Cherry_MX_PCB; not fitted
Spare0, Spare1: SW_Push; SW_Cherry_MX_PCB; not fitted
T_{L}0: SW_Push; SW_Cherry_MX_PCB; not fitted
W0: SW_Push; SW_Cherry_MX_PCB; not fitted

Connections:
/Columns0: D_{Spare}1.1 (K), D_{S}0.1 (K), D_{S}1.1 (K); also elsewhere on the board
/Columns1: D_{K}0.1 (K), D_{Spare}0.1 (K), D_{TL}0.1 (K); also elsewhere on the board
/Columns2: D_{NUM}0.1 (K), D_{PL}0.1 (K), D_{W}0.1 (K); also elsewhere on the board
/Columns3: D_{A}0.1 (K), D_{H}0.1 (K), D_{RL}0.1 (K); also elsewhere on the board
/Columns4: D_{AS}1.1 (K), D_{As}0.1 (K), D_{O}0.1 (K); also elsewhere on the board
/Rows0: Asterisk0.1, H0.1, P_{L}0.1, S0.1, T_{L}0.1; also elsewhere on the board
/Rows1: Asterisk1.1, K0.1, R_{L}0.1, S1.1, W0.1; also elsewhere on the board
/Rows2: A0.1, Number_Bar0.1, Number_Bar1.1, Number_Bar2.1, Number_Bar3.1, Number_Bar4.1, Number_Bar5.1, O0.1, Spare0.1, Spare1.1; also elsewhere on the board
unnamed: Asterisk1.2, D_{AS}1.2 (A)
unnamed: Asterisk0.2, D_{As}0.2 (A)
unnamed: A0.2, D_{A}0.2 (A)
unnamed: D_{H}0.2 (A), H0.2
unnamed: D_{K}0.2 (A), K0.2
unnamed: D_{NUM}0.2 (A), Number_Bar0.2, Number_Bar1.2, Number_Bar2.2, Number_Bar3.2, Number_Bar4.2, Number_Bar5.2
unnamed: D_{O}0.2 (A), O0.2
unnamed: D_{PL}0.2 (A), P_{L}0.2
unnamed: D_{RL}0.2 (A), R_{L}0.2
unnamed: D_{Spare}0.2 (A), Spare0.2
unnamed: D_{Spare}1.2 (A), Spare1.2
unnamed: D_{S}0.2 (A), S0.2
unnamed: D_{S}1.2 (A), S1.2
unnamed: D_{TL}0.2 (A), T_{L}0.2
unnamed: D_{W}0.2 (A), W0.2

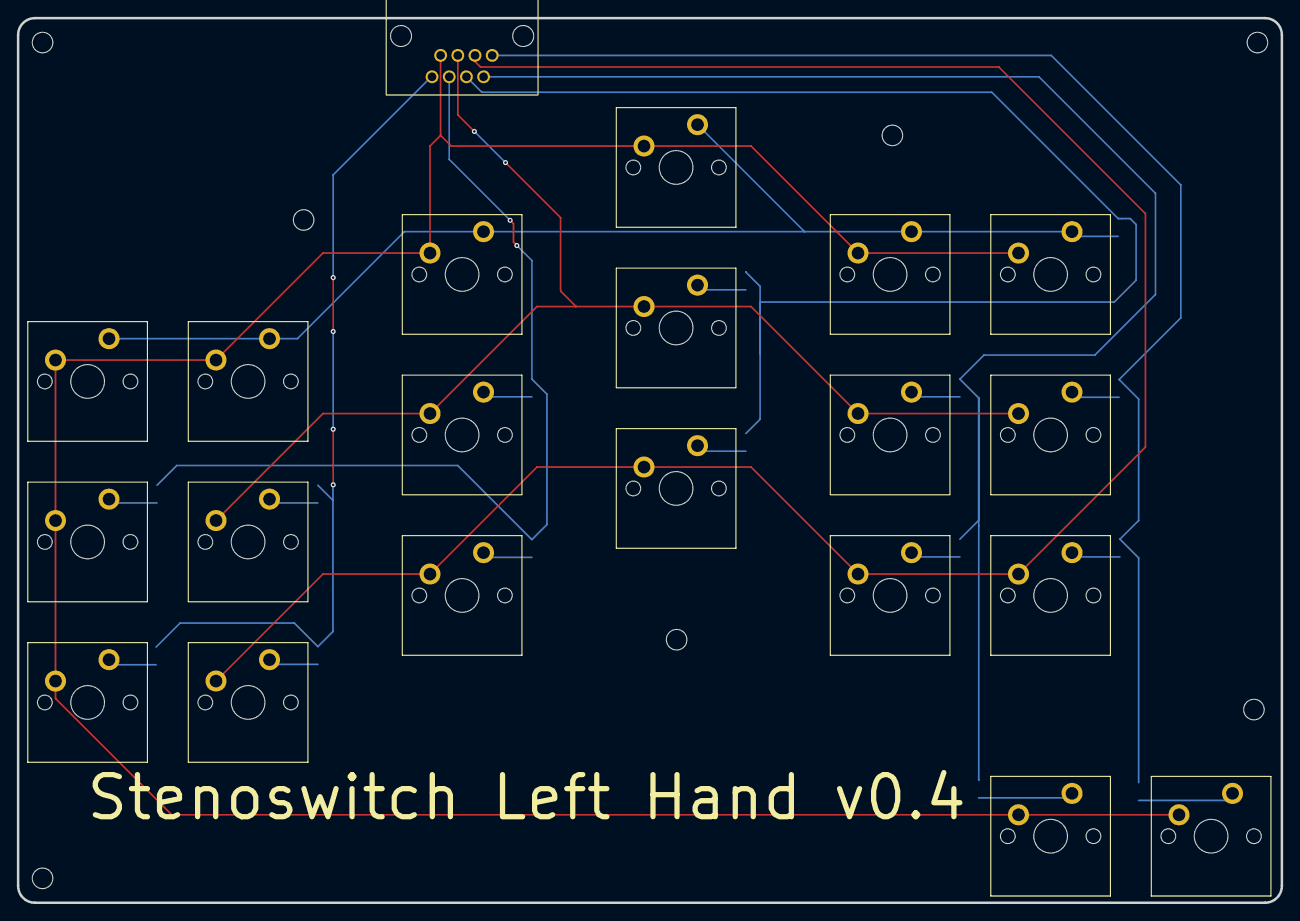
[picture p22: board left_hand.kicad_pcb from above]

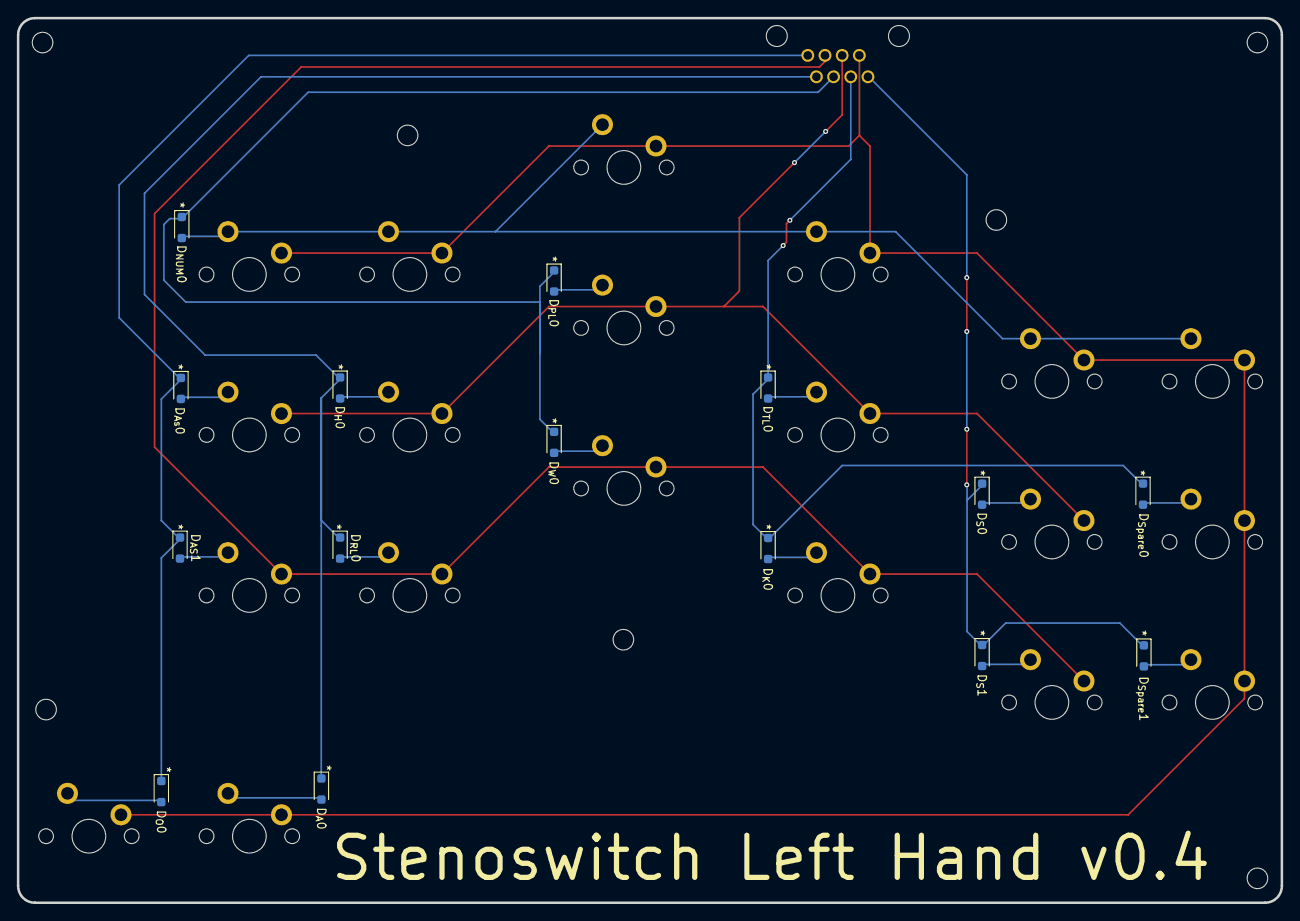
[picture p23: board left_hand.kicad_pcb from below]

Board: 2 copper layers, 150.0 x 105.0 mm, 36 parts (15 on the bottom side), 23 nets.

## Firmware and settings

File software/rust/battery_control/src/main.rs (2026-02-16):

mod battery_monitor;
mod chg_en;
mod current_monitor;
mod current_rheostat;
mod i2c;
mod notify_lines;

use std::{
    error::Error,
    mem,
    process::exit,
    sync::{
        LazyLock, Mutex,
        atomic::{AtomicBool, Ordering},
    },
    thread::{self, sleep},
    time::Duration,
};

use bare_err_tree::{AsErrTree, WrapErr};
use log::{debug, error, info, warn};
use systemd_journal_logger::JournalLog;

use crate::{
    battery_monitor::BatteryMonitor,
    chg_en::ChgEn,
    current_monitor::CurrentMonitor,
    current_rheostat::CurrentRheostat,
    i2c::I2C,
    notify_lines::{NotifyLines, NotifySource},
};

const STORAGE_CHARGE_LIMIT_MILLIVOLTS: u16 = 3700;
const I2C_HERTZ: u32 = 400_000;

#[track_caller]
pub fn bare_err_unwrap<T, E>(res: Result<T, E>) -> T
where
    E: AsErrTree,
{
    const ERROR_DEPTH: usize = 10;
    bare_err_tree::tree_unwrap::<{ ERROR_DEPTH * 6 }, _, _>(res)
}

#[track_caller]
pub fn std_unwrap<T, E>(res: Result<T, E>) -> T
where
    E: Error,
{
    bare_err_unwrap(res.map_err(WrapErr))
}

/// Calibrates the charging rheostat based on the CC pins.
///
/// Will block to for the necessary spacing.
///
/// Even stepping to the rheostat max, this should execute in under a second.
fn set_rheostat_from_cc(
    chg_en: &ChgEn,
    cur_rheostat: &mut CurrentRheostat,
    cur_mon: &mut CurrentMonitor,
) {
    // Always start by setting to a safe maximum
    bare_err_unwrap(cur_rheostat.set_max());

    // Sleep until the current limit can actually be read.
    while !std_unwrap(cur_mon.current_limit_energized()) {
        // Current limit will never energize if charging is disabled.
        // Prevent infinite looping.
        if !std_unwrap(chg_en.is_enabled()) {
            return;
        }

        debug!("Waiting for current limit to energize...");
        sleep(Duration::from_secs(1));
    }

    let cc_limit = |cur_mon: &mut CurrentMonitor| std_unwrap(cur_mon.read_cc()).to_amps();
    let current_limit = |cur_mon: &mut CurrentMonitor| std_unwrap(cur_mon.read_current_limit());

    while current_limit(cur_mon) < cc_limit(cur_mon) {
        // Prevent infinite loops if the rheostat can't raise far enough.
        if cur_rheostat.setting() >= current_rheostat::CUR_LIMIT_MAX {
            warn!(
                "Rheostat topped out below target limit: {} < {}",
                std_unwrap(cur_mon.read_current_limit()),
                cc_limit(cur_mon)
            );
            break;
        }
        bare_err_unwrap(cur_rheostat.step_up());
        sleep(current_rheostat::WIPER_SET_WAIT);
    }

    while current_limit(cur_mon) > cc_limit(cur_mon) {
        // Prevent infinite loops if the rheostat can't lower far enough.
        if cur_rheostat.setting() == 0 {
            error!(
                "Rheostat bottomed out above target limit: {} < {}",
                std_unwrap(cur_mon.read_current_limit()),
                cc_limit(cur_mon)
            );
            break;
        }
        bare_err_unwrap(cur_rheostat.step_down());
        sleep(current_rheostat::WIPER_SET_WAIT);
    }
}

/// Gets new stats from the battery.
///
/// Returns the raw state of charge.
/// TODO battery monitor status stuff
/// Should be doing writes to a SQLite database in /tmp/
/// This can be used for data displayed over Bluetooth etc.
/// Probably also have files in mass storage filesystem with
/// some of this info.
/// And/or capture in special log fake device.
fn update_battery_stats(
    bat_mon: &mut BatteryMonitor,
    is_discharging: bool,
) -> battery_monitor::Percent {
    let raw_soc = bare_err_unwrap(bat_mon.raw_state_of_charge());
    debug!(
        "Battery stats: {:?}% charge, {}% raw charge, {}% of design, {} mV, {} mA, {} mW",
        bat_mon.state_of_charge(raw_soc, is_discharging),
        raw_soc,
        (bare_err_unwrap(bat_mon.full_available_capacity()) as f32)
            / (battery_monitor::BATTERY_DESIGN_CAPACITY as f32),
        bare_err_unwrap(bat_mon.millivolts()),
        bare_err_unwrap(bat_mon.average_current()),
        bare_err_unwrap(bat_mon.average_power()),
    );

    raw_soc
}

fn main() {
    static CHG_EN: LazyLock<ChgEn> = LazyLock::new(|| std_unwrap(ChgEn::new()));

    static I2C_BUS: LazyLock<Mutex<I2C>> = LazyLock::new(|| {
        info!("Intializing I2C bus...");
        let sda_pin = std_unwrap(str::parse(option_env!("SDA_PIN").unwrap_or("/dev/null")));
        let scl_pin = std_unwrap(str::parse(option_env!("SCL_PIN").unwrap_or("/dev/null")));
        Mutex::new(bare_err_unwrap(I2C::new(I2C_HERTZ, sda_pin, scl_pin)))
    });

    // ---------------------------------- //
    // Establish safe state on the En pin //
    // ---------------------------------- //
    std_unwrap(CHG_EN.disable());

    // Disable charging on panic
    let default_panic = std::panic::take_hook();
    std::panic::set_hook(Box::new(move |info| {
        if let Err(e) = CHG_EN.disable() {
            error!("Failed to disable charging on panic! {e:#?}");
        };
        default_panic(info);
        // Child threads also terminate the program.
        exit(1);
    }));

    // Try disabling charge just once on Ctrl-C
    std_unwrap(ctrlc::set_handler(|| {
        if let Err(e) = CHG_EN.disable() {
            error!("Failed to disable charging on ctrl-c! {e:#?}");
        };
        exit(2);
    }));

    // ---------------------------------- //

    std_unwrap(std_unwrap(JournalLog::new()).install());
    log::set_max_level(if cfg!(debug_assertions) {
        log::LevelFilter::Trace
    } else {
        log::LevelFilter::Info
    });

    // This repeats the earlier initialization set.
    info!("Set charging to pre-setup disable");
    CHG_EN.disable().unwrap();

    info!("Intializing SPI and I2C devices...");
    let (cur_rheostat, bat_mon, mut cur_mon) = thread::scope(|s| {
        // SPI can occur at the same time as I2C communications.
        let current_thread = s.spawn(|| std_unwrap(CurrentMonitor::new()));

        (
            Mutex::new(
                std::iter::from_fn(|| {
                    Some(match CurrentRheostat::new(&I2C_BUS) {
                        Ok(rheo) => Some(rheo),
                        Err(e) => {
                            error!("Rheostat init failure: {e:#?}");
                            std::thread::sleep(Duration::from_millis(500));
                            std_unwrap(std_unwrap(I2C_BUS.lock()).reset());
                            std::thread::sleep(Duration::from_millis(500));
                            None
                        }
                    })
                })
                .flatten()
                .next()
                .unwrap(),
            ),
            Mutex::new(bare_err_unwrap(BatteryMonitor::new(&I2C_BUS))),
            current_thread.join().unwrap(),
        )
    });
    info!("Initialized SPI and I2C devices");
    sd_notify::notify(true, &[sd_notify::NotifyState::Ready]).unwrap();

    let cur_mon = Mutex::new(cur_mon);
    let notify_lines = NotifyLines::new();
    let storage_voltage = AtomicBool::new(false);
    let charging = AtomicBool::new(false);
    thread::scope(|s| {
        let mut charge_enabled_thread = s.spawn(|| {});

        let _ = s.spawn(|| {
            let mut bat_mon = bat_mon.lock().unwrap();
            update_battery_stats(&mut bat_mon, !charging.load(Ordering::Relaxed))
        });

        loop {
            // Ongoing states
            if log::max_level() >= log::LevelFilter::Debug {
                let mut cur_mon = cur_mon.lock().unwrap();
                debug!("CC Lines: {:?}", cur_mon.read_cc());
                debug!("Current limit = {:?} amps", cur_mon.read_current_limit());
            }

            let notification = notify_lines.next_notification();
            match notification.source {
                NotifySource::Batmon => {
                    debug!("Battery monitor notification");

                    let _ = s.spawn(|| {
                        let mut bat_mon = bat_mon.lock().unwrap();
                        let raw_soc =
                            update_battery_stats(&mut bat_mon, !charging.load(Ordering::Relaxed));

                        let storage_stop = storage_voltage.load(Ordering::Relaxed)
                            && (bare_err_unwrap(bat_mon.millivolts())
                                > STORAGE_CHARGE_LIMIT_MILLIVOLTS);
                        let soc_stop = raw_soc >= bat_mon.state_of_charge_max();
                        drop(bat_mon); // No need to hold the mutex past this point.

                        let disable_charging = soc_stop || storage_stop;
                        let prev_charge_state = charging.swap(!disable_charging, Ordering::Relaxed);

                        // If they match, the charging state flipped.
                        if disable_charging == prev_charge_state {
                            if disable_charging {
                                std_unwrap(CHG_EN.disable());
                                info!("Battery beyond limits, turned off charging");
                            } else {
                                std_unwrap(CHG_EN.enable());
                                info!("Battery fell below limits, turned on charging");
                            }
                        }
                    });
                }
                NotifySource::ChgOn => {
                    if !notification.value {
                        info!("Started charging battery from USB")
                    } else {
                        info!("Stopped charging battery from USB")
                    }
                }
                NotifySource::UsbOn => {
                    // Always start USB power changes by setting to a safe state.
                    // If USB was connected, this prevents overdrawing.
                    // If USB was disconnected, this is extra protection for the
                    // next connection.
                    std_unwrap(CHG_EN.disable());

                    // Tune the charge limit when USB is attached AND there
                    // isn't an existing tuning thread.
                    // Skipping the tuning thread check could cause
                    // uncontrolled thread spawning.
                    if (!notification.value) && charge_enabled_thread.is_finished() {
                        let old_thread = mem::replace(
                            &mut charge_enabled_thread,
                            s.spawn(|| {
                                info!("Switched to USB power");

                                let skip_charging = s.spawn(|| {
                                    let mut bat_mon = bat_mon.lock().unwrap();
                                    //bare_err_unwrap(bat_mon.sleep(false));
                                    //info!("Turned off battery monitor sleep");

                                    let storage_stop = storage_voltage.load(Ordering::Relaxed)
                                        && (bare_err_unwrap(bat_mon.millivolts())
                                            > STORAGE_CHARGE_LIMIT_MILLIVOLTS);
                                    let soc_stop = bare_err_unwrap(bat_mon.raw_state_of_charge())
                                        >= bat_mon.state_of_charge_max();

                                    storage_stop || soc_stop
                                });

                                let skip_charging = skip_charging.join().unwrap();
                                charging.store(!skip_charging, Ordering::Relaxed);
                                if skip_charging {
                                    info!("Battery beyond limits, keeping charging disabled");
                                } else {
                                    {
                                        let mut cur_rheostat = std_unwrap(cur_rheostat.lock());
                                        let mut cur_mon = std_unwrap(cur_mon.lock());

                                        std_unwrap(cur_rheostat.set_max());

                                        std_unwrap(CHG_EN.enable());
                                        info!("Enabled charging");

                                        let cc_limit = std_unwrap(cur_mon.read_cc());

                                        set_rheostat_from_cc(
                                            &CHG_EN,
                                            &mut cur_rheostat,
                                            &mut cur_mon,
                                        );
                                        info!(
                                            "Configured rheostat with {} mA limit",
                                            cc_limit.to_milliamps()
                                        );

                                        // TODO: spawn background thread that watches for a cc
                                        // change and reruns rheostat set.
                                    }
                                }
                            }),
                        );

                        // Catch any panic from the previous invocation.
                        old_thread.join().unwrap();
                    }
                }
                NotifySource::BatOn => {
                    if !notification.value {
                        info!("Switched to battery power");
                        let _ = s.spawn(|| {
                            //bare_err_unwrap(bat_mon.lock().unwrap().sleep(true));
                            //info!("Turned on battery monitor sleep");
                        });
                    }
                }
                NotifySource::StoreOn => {
                    storage_voltage.store(notification.value, Ordering::Relaxed);

                    if notification.value {
                        info!("Set battery charging to stop at 3.7 V");
                    } else {
                        info!("Set battery charging to stop at configured max state of charge");
                    };
                }
            }
        }
    });
}

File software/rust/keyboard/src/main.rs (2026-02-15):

#![feature(portable_simd)]

use std::{fs::remove_file, io::Write, process::Command, sync::mpsc, thread, time::Duration};

use log::{debug, info};
use serialport::{Parity, SerialPort};
use systemd_journal_logger::JournalLog;
use virtual_serialport::VirtualPort;

use crate::scan::KeyScanner;

mod scan;

// General fastest baud for serial protocols.
const GEMINI_BAUD_RATE: u32 = 115_200;
// Arbitrary.
const SERIAL_BUFFER_SIZE: u32 = 1024;
// Arbitrary.
const PACKET_DELAY_SIZE: usize = 1024;

fn main() {
    JournalLog::new().unwrap().install().unwrap();
    log::set_max_level(if cfg!(debug_assertions) {
        log::LevelFilter::Trace
    } else {
        log::LevelFilter::Info
    });

    let (put, recv) = mpsc::sync_channel(PACKET_DELAY_SIZE);

    thread::spawn(move || {
        let mut scanner = KeyScanner::new().unwrap();
        info!("Initialized key scanner");

        scanner.verify_scan();

        loop {
            scanner.wait_for_input();
            let packet = scanner.scan().unwrap();
            debug!("Gemini packet: {packet:?}");
            put.send(packet).unwrap();
        }
    });

    let _ = remove_file("/tmp/ttyKeyboardIn");
    let _ = remove_file("/tmp/ttyKeyboardOut");
    /*
    let _socat = Command::new("socat")
        .args([
            "pty,rawer,link=/tmp/ttyKeyboardIn,b115200",
            "pty,rawer,link=/tmp/ttyKeyboardOut,b115200",
        ])
        .spawn()
        .unwrap();
    */

    let mut port = VirtualPort::loopback(GEMINI_BAUD_RATE, SERIAL_BUFFER_SIZE).unwrap();
    info!("Initialized virtual port");

    sd_notify::notify(true, &[sd_notify::NotifyState::Ready]).unwrap();

    loop {
        let packet = recv.recv().unwrap();
        debug!("Recv packet: {packet:?}");
        port.write(&*packet).unwrap();
    }
}

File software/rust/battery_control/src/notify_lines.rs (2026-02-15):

use std::sync::mpsc;

use gpio_cdev::{Chip, EventRequestFlags, EventType, LineRequestFlags};
use log::debug;

const BATMON_LINE: &str = if let Some(x) = option_env!("ALERT_BATMON") {
    x
} else {
    "NaN"
};
const CHG_ON_LINE: &str = if let Some(x) = option_env!("CHG_ON") {
    x
} else {
    "NaN "
};
const USB_ON_LINE: &str = if let Some(x) = option_env!("USB_ON") {
    x
} else {
    "NaN "
};
const BAT_ON_LINE: &str = if let Some(x) = option_env!("BAT_ON") {
    x
} else {
    "NaN "
};
const STORE_ON_LINE: &str = if let Some(x) = option_env!("STORE_ON") {
    x
} else {
    "NaN "
};

#[derive(Debug, Clone, Copy, PartialEq, Eq, PartialOrd, Ord, Hash)]
pub enum NotifySource {
    Batmon,
    ChgOn,
    UsbOn,
    BatOn,
    StoreOn,
}

#[derive(Debug, Clone, Copy, PartialEq, Eq, PartialOrd, Ord, Hash)]
pub struct LineNotification {
    pub source: NotifySource,
    pub value: bool,
}

pub struct NotifyLines {
    notifications: mpsc::Receiver<LineNotification>,
}

impl NotifyLines {
    /// Creates a line monitor, panicking on hardware failures.
    pub fn new() -> Self {
        let (tx, rx) = mpsc::sync_channel(0);

        let mut chip = Chip::new(option_env!("GPIO_CHIP").unwrap_or("/dev/null")).unwrap();

        let _both_edges = [
            (CHG_ON_LINE, NotifySource::ChgOn),
            (USB_ON_LINE, NotifySource::UsbOn),
            (BAT_ON_LINE, NotifySource::BatOn),
            (STORE_ON_LINE, NotifySource::StoreOn),
        ]
        .map(|(line, source)| {
            let tx = tx.clone();
            let line = chip.get_line(str::parse(line).unwrap()).unwrap();
            std::thread::spawn(move || {
                let events = line
                    .events(
                        LineRequestFlags::INPUT.union(LineRequestFlags::BIAS_PULL_UP),
                        EventRequestFlags::BOTH_EDGES,
                        &format!("battery_control {:?}", source),
                    )
                    .unwrap();

                let init_value = events.get_value().unwrap() != 0;
                tx.send(LineNotification {
                    source,
                    value: init_value,
                })
                .unwrap();

                for event in events {
                    let value = match event.unwrap().event_type() {
                        EventType::RisingEdge => true,
                        EventType::FallingEdge => false,
                    };
                    debug!("Line event: {source:#?} -> {value}");
                    tx.send(LineNotification { source, value }).unwrap();
                }
            })
        });

        let _batmon = {
            let line = chip.get_line(str::parse(BATMON_LINE).unwrap()).unwrap();
            std::thread::spawn(move || {
                let events = line
                    .events(
                        LineRequestFlags::INPUT.union(LineRequestFlags::BIAS_PULL_UP),
                        EventRequestFlags::FALLING_EDGE,
                        "battery_control BATMON",
                    )
                    .unwrap();

                let init_value = events.get_value().unwrap() != 0;
                tx.send(LineNotification {
                    source: NotifySource::Batmon,
                    value: init_value,
                })
                .unwrap();

                for _event in events {
                    debug!("Line event: {:#?} -> {}", NotifySource::Batmon, false);
                    tx.send(LineNotification {
                        source: NotifySource::Batmon,
                        value: false,
                    })
                    .unwrap();
                }
            })
        };

        Self { notifications: rx }
    }

    /// Blocks until a new notification, then returns that event.
    pub fn next_notification(&self) -> LineNotification {
        let notification = self.notifications.recv().unwrap();
        debug!(
            "Recv line event: {:#?} -> {}",
            notification.source, notification.value
        );
        notification
    }
}

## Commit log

2025-07-30 Core PCB Layout, Incl Key Matrices
    [control.kicad_sch, left_hand.kicad_sch, left_hand_keys.kicad_sch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]
2025-07-30 Label keys
    [left_hand_keys.kicad_sch, right_hand_keys.kicad_sch]
2025-08-04 Design power
    [1042.STEP, 1042.step, DMG2305UX-7.step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]
2025-08-06 Adjust battery resistor values
    [battery.kicad_sch]
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2025-08-07 Remove unnecessary diodes
    [left_hand_keys.kicad_sch, right_hand_keys.kicad_sch]
2025-08-08 Rework battery entirely
    [BQ27427YZFR.STEP, BQ27427YZFR.step, MCP40D19T-104E_LT.step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]
2025-08-09 Assign footprints
    [battery.kicad_sch, control.kicad_sch, interface.kicad_sch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]
2025-08-09 Init right and left PCBs
    [1042.STEP, 1042.step, BQ27427YZFR.STEP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]
2025-08-09 Rename keyswitch diodes
    [battery.kicad_sch, control.kicad_sch, interface.kicad_sch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]
2025-08-09 Layout left hand side
    [942.STEP, left_hand.kicad_pcb, left_hand.kicad_sch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]
2025-08-09 Standardize connector names
    [left_hand.kicad_sch, right_hand.kicad_sch]
2025-08-09 Generate left hand vias
    [left_hand.kicad_pcb]
2025-08-09 Match left hand pins
    [left_hand.kicad_sch, right_hand.kicad_sch]
2025-08-09 Make battery holder thru-hole
    [1043.step, battery.kicad_sch]
2025-08-10 Assign models for right hand
    [DBZ0003A.stp, MP2637GR.step, RA1113xxxR.stp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]
2025-08-10 Put connector on front
    [left_hand.kicad_pcb]
2025-08-10 Size up components
    [battery.kicad_sch, interface.kicad_sch, right_hand.kicad_pcb]
2025-08-10 Place right hand keys
    [right_hand.kicad_pcb]
2025-08-25 Complete most of RHS layout
    [FUSE_ERBRE_PAN.step, battery.kicad_sch, control.kicad_sch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]
2025-08-30 Rework left hand
    [left_hand.kicad_pcb, left_hand.step]
2025-08-30 Rework right hand
    [0926-1-15-20-75-14-11-0.step, 61304021121+(rev1).stp, DPL0002A.stp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]
2025-08-30 Replace USB connector
    [control.kicad_sch, interface.kicad_sch, right_hand.kicad_pcb]
2025-08-30 Add labeling
    [right_hand.kicad_pcb]
2025-09-05 Update libraries
    [B64290P0037X087.step]
2025-09-05 Update layout
    [battery.kicad_sch, control.kicad_sch, interface.kicad_sch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]
2025-09-05 Add holes to stencil
    [left_hand.kicad_pcb, left_hand.step, right_hand.kicad_pcb]
2025-09-05 Plot according to JLC rules
    [left_hand.kicad_pcb, right_hand.kicad_pcb]
2025-09-05 Rename core files
    [stenoswitch.kicad_sch]
2025-09-06 Add parts list
    [bom.csv, digikey.csv, portable_steno.csv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]
2025-09-06 Make PCB subdirectory
    [0926-1-15-20-75-14-11-0.step, 1042.STEP, 1042.step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]
2025-09-07 Create README file and assembly dir
    [bom.csv, digikey.csv, recommended.csv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]
2025-09-16 Generate wifi-debuggable image
    [squashfs.cfg]
2025-09-19 Add prototype keycap
    [bom.csv, digikey.csv, keycap.FCStd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]
2025-10-06 Add 3D printed fixtures
    [base_plate.3mf, base_plate.FCStd, base_plate.stl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]
2025-10-21 Make left hand pads larger
    [left_hand.kicad_pcb]
2025-10-21 Plate right hand mounting holes
    [right_hand.kicad_pcb]
2025-10-21 Fix Bluetooh Enable positioning
    [right_hand.kicad_pcb]
2025-10-21 Make right hand pads larger
    [right_hand.kicad_pcb]
2025-10-21 Right hand DRC check fixes
    [right_hand.kicad_pcb]
2025-10-21 Left hand plate mounting holes
    [left_hand.kicad_pcb]
2025-10-21 Rework footprints
    [right_hand.kicad_pcb]
2025-10-21 Change ESD layout
    [right_hand.kicad_pcb]
2025-10-21 Enlarge VSYS TVS footprint
    [right_hand.kicad_pcb]
2025-10-21 Extra right hand tweaks and cleanup
    [right_hand.kicad_pcb]
2025-10-21 Update right hand metadata
    [right_hand.kicad_pcb]
2025-10-21 Readjust positive data ESD
    [right_hand.kicad_pcb]
2025-10-21 Add more ESD protection
    [battery.kicad_sch, control.kicad_sch, interface.kicad_sch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]
2025-10-21 Connect right_columns 2 to RPi
    [control.kicad_sch, right_hand.kicad_pcb]
2025-10-21 Ground right hand through holes
    [right_hand.kicad_pcb]
2025-10-21 Move toggle switches closer together
    [right_hand.kicad_pcb]
2025-10-21 Extra copper
    [right_hand.kicad_pcb]
2025-10-21 Plate left hand through holes
    [left_hand.kicad_pcb, left_hand.kicad_sch, left_hand.step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]
2025-10-23 Update parts counts
    [bom.csv, digikey.csv]
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2025-10-30 Replace env with option_env
    [battery_monitor.rs, chg_en.rs, current_monitor.rs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]
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2025-11-02 Fix SPI overlay to use built in
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2025-11-04 Enable USB gadget
    [usb_gadget.cfg]
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2025-11-04 Create plover config by default
    [plover.cfg]
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2025-11-10 Update PCB to connect 4th right column
    [control.kicad_sch, right_hand.kicad_pcb]
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2025-11-10 Implement keyboard scanning
    [battery.kicad_sch, control.kicad_sch, interface.kicad_sch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]
2025-11-10 Fix i2c frequency
2025-11-14 Soft link right hand to primary copy
    [battery.kicad_sch, right_hand.kicad_pcb]
2025-11-14 Label parts for JLCPCB
    [battery.kicad_sch, control.kicad_sch, interface.kicad_sch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]
2025-11-14 Adjust left hand silkscreen; holes
    [left_hand.kicad_pcb]
2025-11-14 Generate left_hand v0.4 for assembly
    [left_hand.kicad_pcb]
2025-11-14 Add DNP for right hand
    [battery.kicad_sch, control.kicad_sch, interface.kicad_sch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]
2025-11-15 Adjust right hand mounts, testpoints
    [right_hand.kicad_pcb]
2025-11-15 Relabel right hand
    [interface.kicad_sch, right_hand.kicad_pcb]
2025-11-15 Shrink one problem hole
    [right_hand.kicad_pcb]
2025-11-15 Mark misc do not populate
    [right_hand.kicad_pcb]
2025-11-16 Prep for assembly ordering
    [right_hand.kicad_pcb]
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2025-11-16 Create variant for jlcpcb cost golf
    [battery.kicad_sch, control.kicad_sch, interface.kicad_sch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]
2025-11-16 Label LCSC
    [battery.kicad_sch, control.kicad_sch, interface.kicad_sch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]
2025-11-16 Create right hand order for JLCPCB
    [battery.kicad_sch, control.kicad_sch, right_hand.kicad_pcb]
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2025-11-19 Rework and flesh out keyboard scanning
    [main.rs, scan.rs]
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2025-11-24 Increase plover gemini PR baud rate
    [plover.cfg]
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2026-01-20 Implement base USB commns; fix timestamps
    [main.rs, scan.rs]
2026-01-20 Fix pin logic
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2026-02-15 Rework I2C and battery monitor
    [battery_monitor.rs, current_monitor.rs, current_rheostat.rs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]
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2026-02-16 Clock when SDA is stuck
    [battery_monitor.rs, i2c.rs, main.rs]
2026-02-16 Avoid crashes before charging is enabled
    [chg_en.rs, current_monitor.rs, main.rs]
2026-02-16 Charging fixes
2026-02-17 Add microsd flip flex PCB
    [MSD-10-C.step, microsd_flipper.3mf, microsd_flipper.kicad_pcb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]
2026-02-20 Create stencil for microsd flipper
    [microsd_flipper.kicad_pcb, microsd_flipper_stencil.kicad_pcb]
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2026-06-07 Add hacked together stand
    [stand.3mf, stand.FCStd, stand.stl]

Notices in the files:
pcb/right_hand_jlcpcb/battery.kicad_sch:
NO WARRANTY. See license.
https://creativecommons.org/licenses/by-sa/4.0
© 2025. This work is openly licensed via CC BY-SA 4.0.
